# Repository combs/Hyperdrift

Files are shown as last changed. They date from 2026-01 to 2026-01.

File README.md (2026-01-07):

Hyperdrift is a panelized LED matrix artwork.

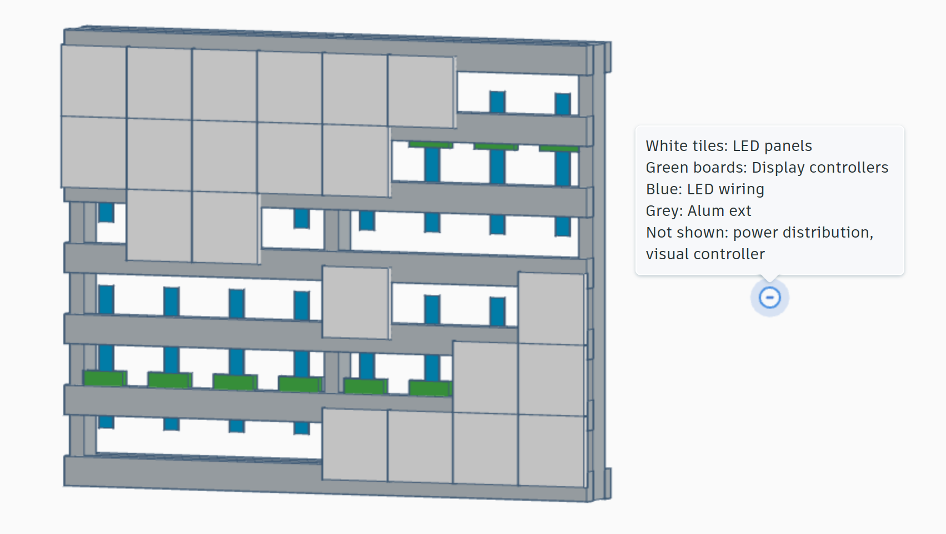
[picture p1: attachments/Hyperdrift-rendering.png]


# LED panels
Each panel can have an arbitrary layout of LEDs, as long as they are electrically connected in a 4x16 matrix (4 common cathodes, 16 anodes).

## Mechanical specification

- [Spec PDF](https://github.com/combs/Hyperdrift/raw/refs/heads/main/Mechanical%20specs/Hyperdrift-Mechanical%20spec%20for%20LED%20panels.pdf) 

## Example LED panel layouts

### Grid
This is a straightforward grid of 8x8 pixels.
- [KiCad board and schematic](https://github.com/combs/Hyperdrift/tree/main/LED%20panel%20reference%20design%20-%20Grid)
- [BOM](https://github.com/combs/Hyperdrift/raw/refs/heads/main/LED%20panel%20reference%20design%20-%20Grid/bom/ibom.html) (download and open)
- [Schematic PDF](https://github.com/combs/Hyperdrift/raw/refs/heads/main/LED%20panel%20reference%20design%20-%20Grid/Hyperdrift-Grid.pdf) 
- [Board PDF](https://github.com/combs/Hyperdrift/raw/refs/heads/main/LED%20panel%20reference%20design%20-%20Grid/plots/Hyperdrift-Grid__Assembly.pdf) 

# Display controllers

Each display controller is a 75x100mm board that drives three LED panels (12x16 matrix arrangement). It accepts 12V in. It is designed to allow for either daisy-chained or wagon-wheel bus arrangement.

- [KiCad board and schematic](https://github.com/combs/Hyperdrift/tree/main/Display%20controller)
- [BOM](https://github.com/combs/Hyperdrift/raw/refs/heads/main/Display%20controller/bom/ibom.html) (download and open)
- [Schematic PDF](https://github.com/combs/Hyperdrift/raw/refs/heads/main/Display%20controller/Hyperdrift-Display-Controller.pdf) 
- [Board PDF](https://github.com/combs/Hyperdrift/raw/refs/heads/main/Display%20controller/Hyperdrift-Display-Controller-board.pdf)

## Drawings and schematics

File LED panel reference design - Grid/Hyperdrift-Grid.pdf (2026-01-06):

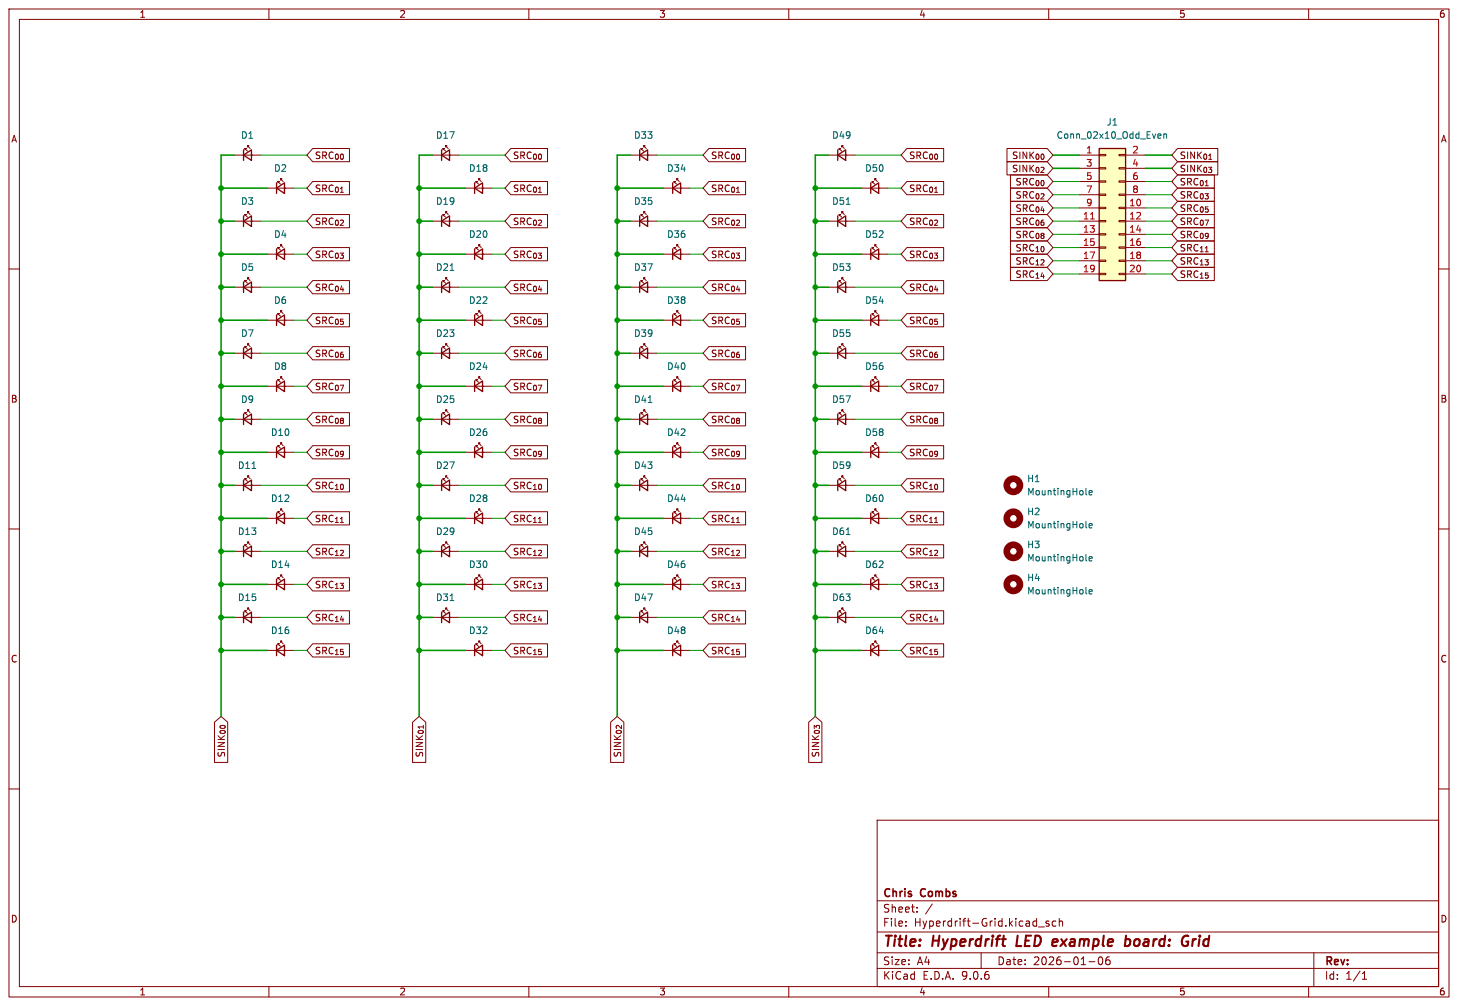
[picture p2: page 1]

Id: 1/1 Title: Hyperdrift LED example board: Grid

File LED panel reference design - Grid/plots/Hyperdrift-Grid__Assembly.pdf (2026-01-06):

A

A

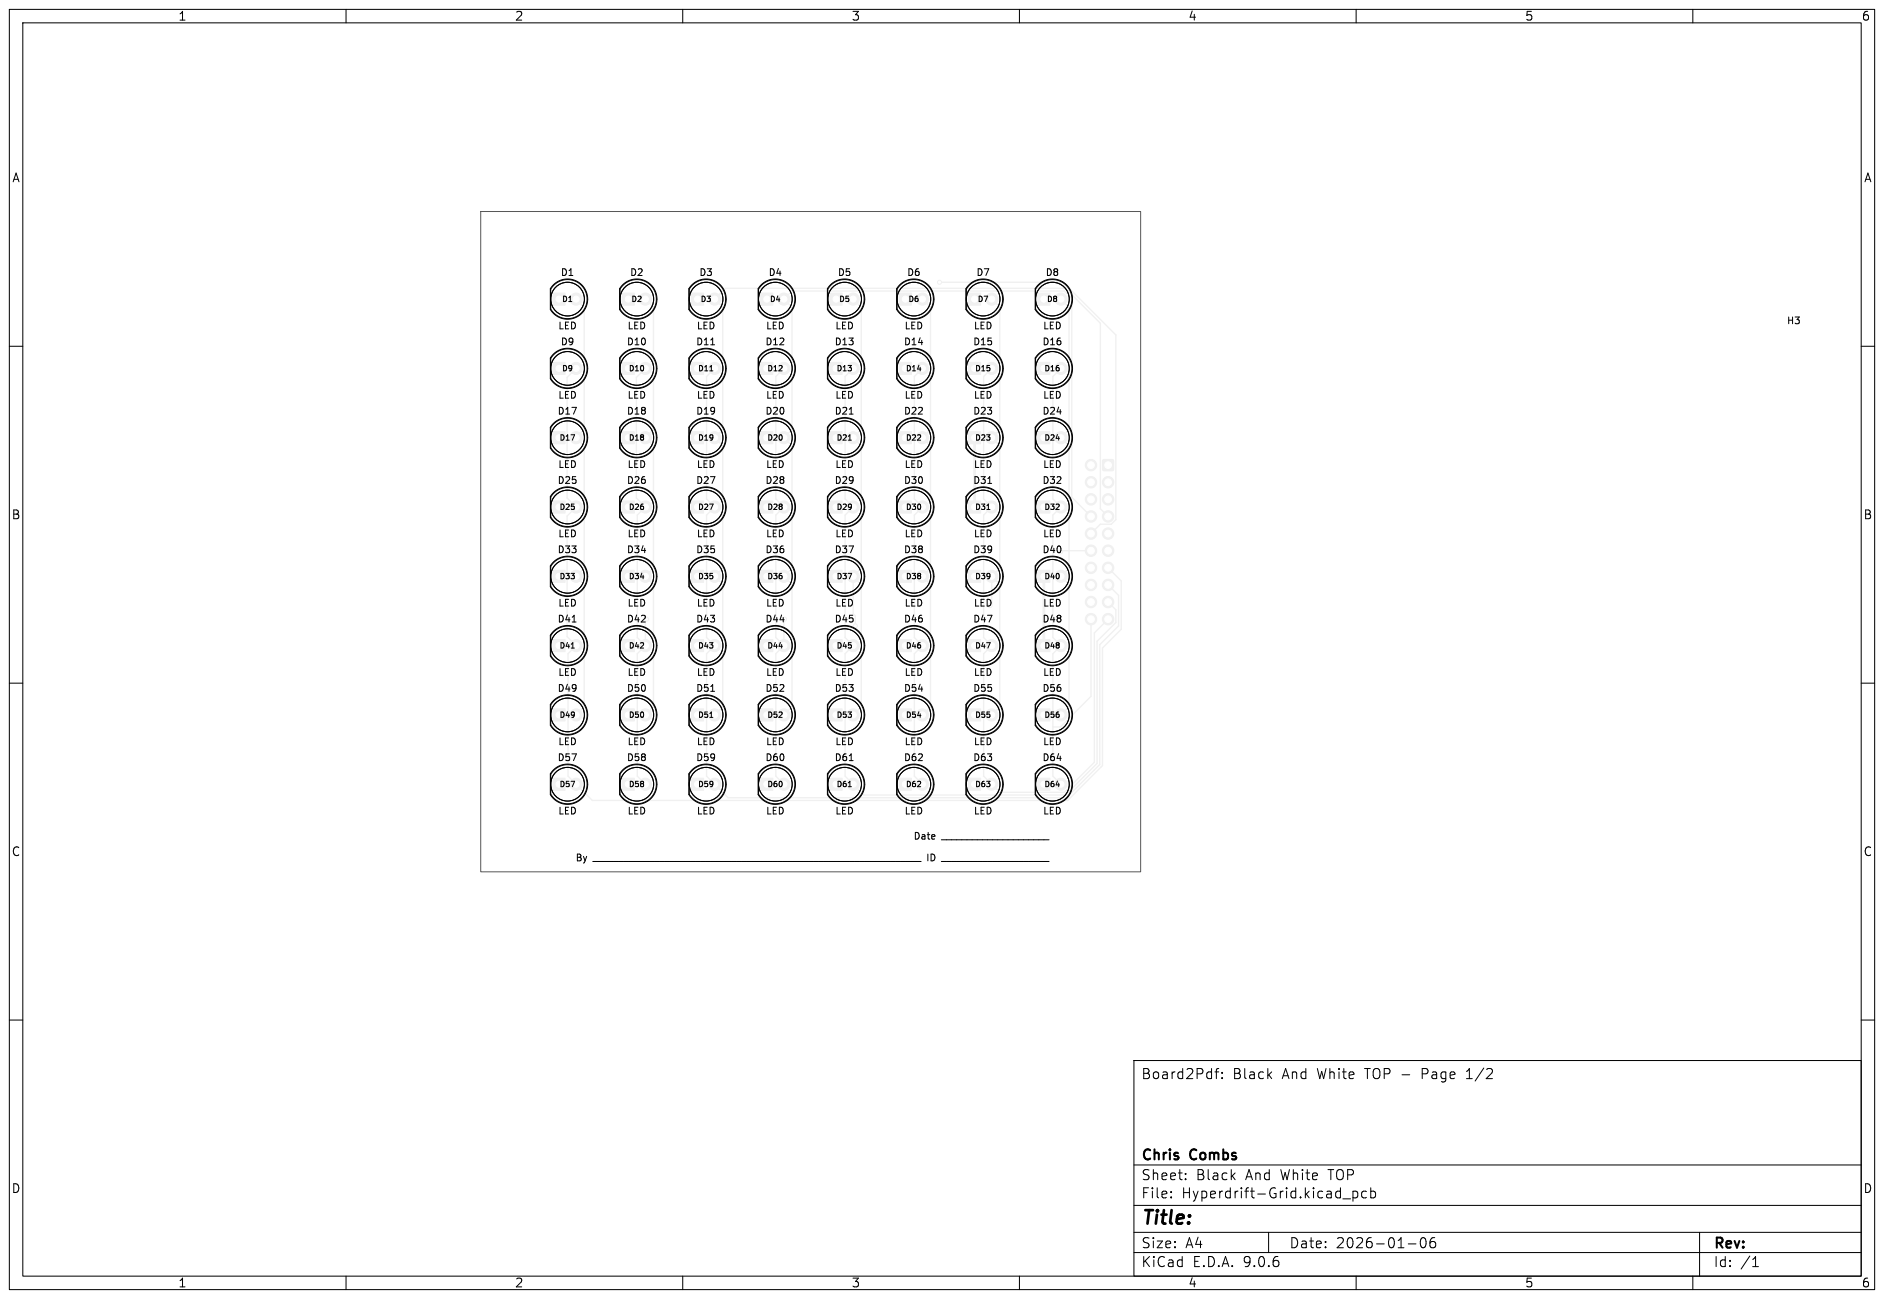
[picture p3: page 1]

J1 1 | 2 | 3 | 4 | 5 | 6

A

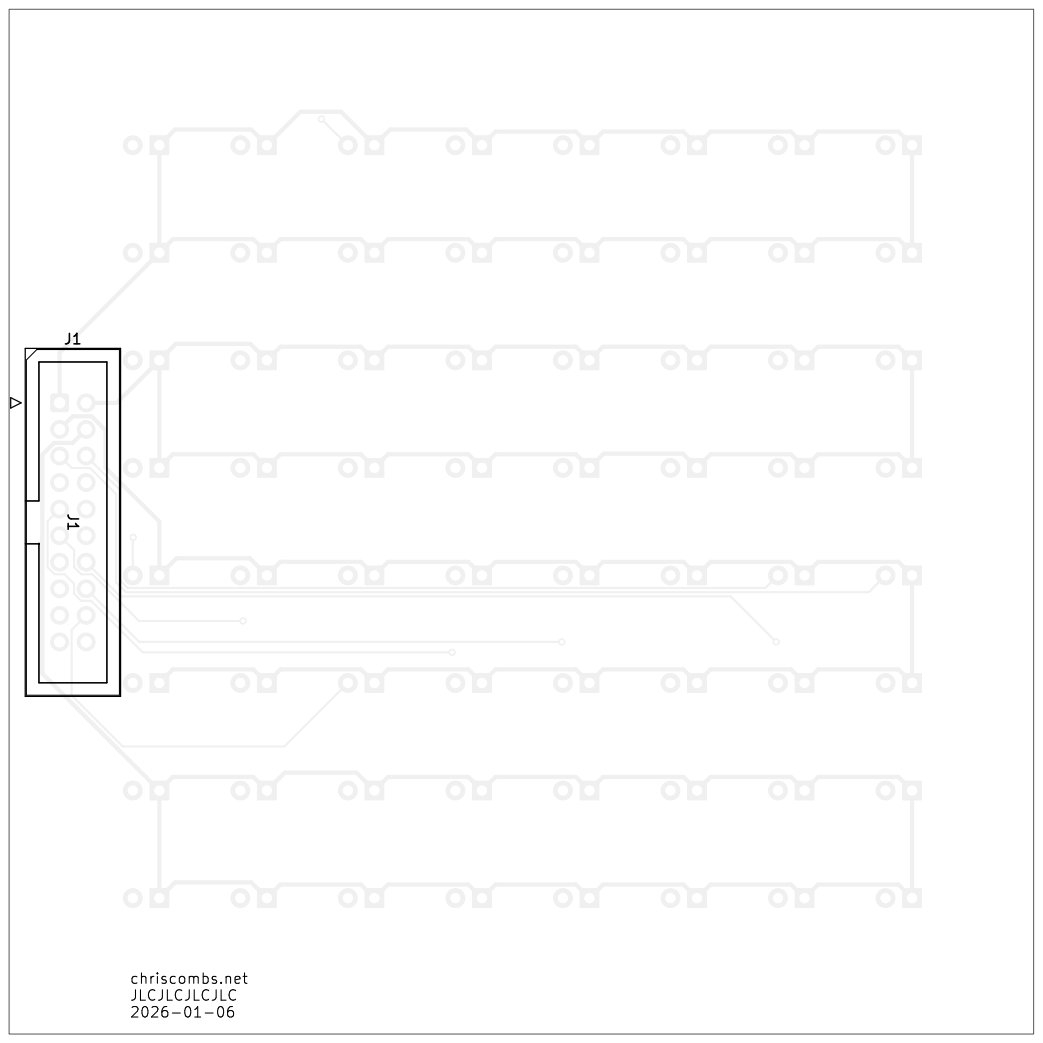
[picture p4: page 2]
D Date: 2026-01-06 KiCad; E.D.A. 9.0.6 Size: A4; Rev:; Id: /1 Title: File: Hyperdrift-Grid.kicad_pcb Sheet: Black; And; White; BOT Chris Combs Board2Pdf:; Black; BOT -; Page 2/2 J1

chriscombs.net JLCJLCJLCJLC

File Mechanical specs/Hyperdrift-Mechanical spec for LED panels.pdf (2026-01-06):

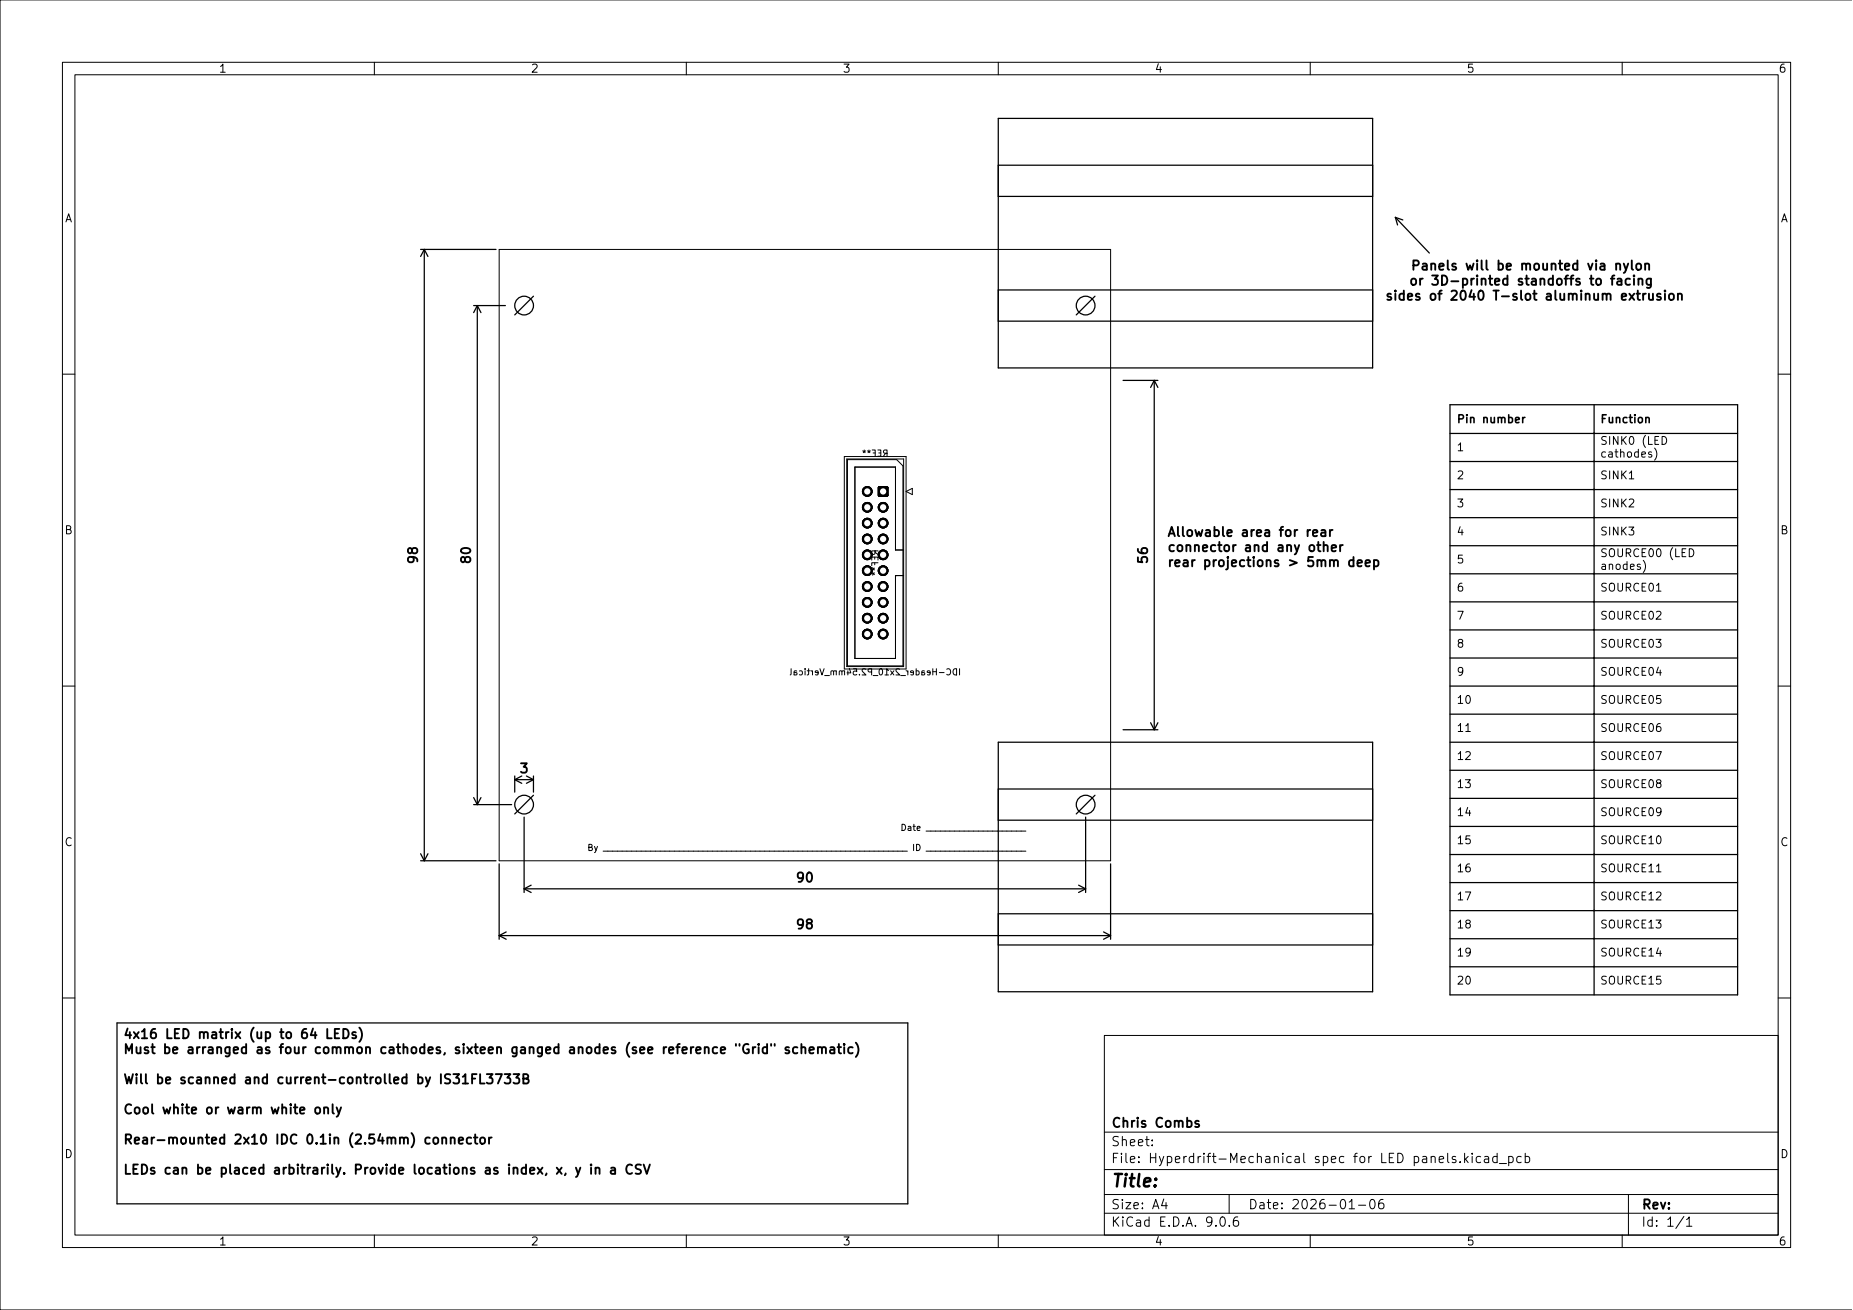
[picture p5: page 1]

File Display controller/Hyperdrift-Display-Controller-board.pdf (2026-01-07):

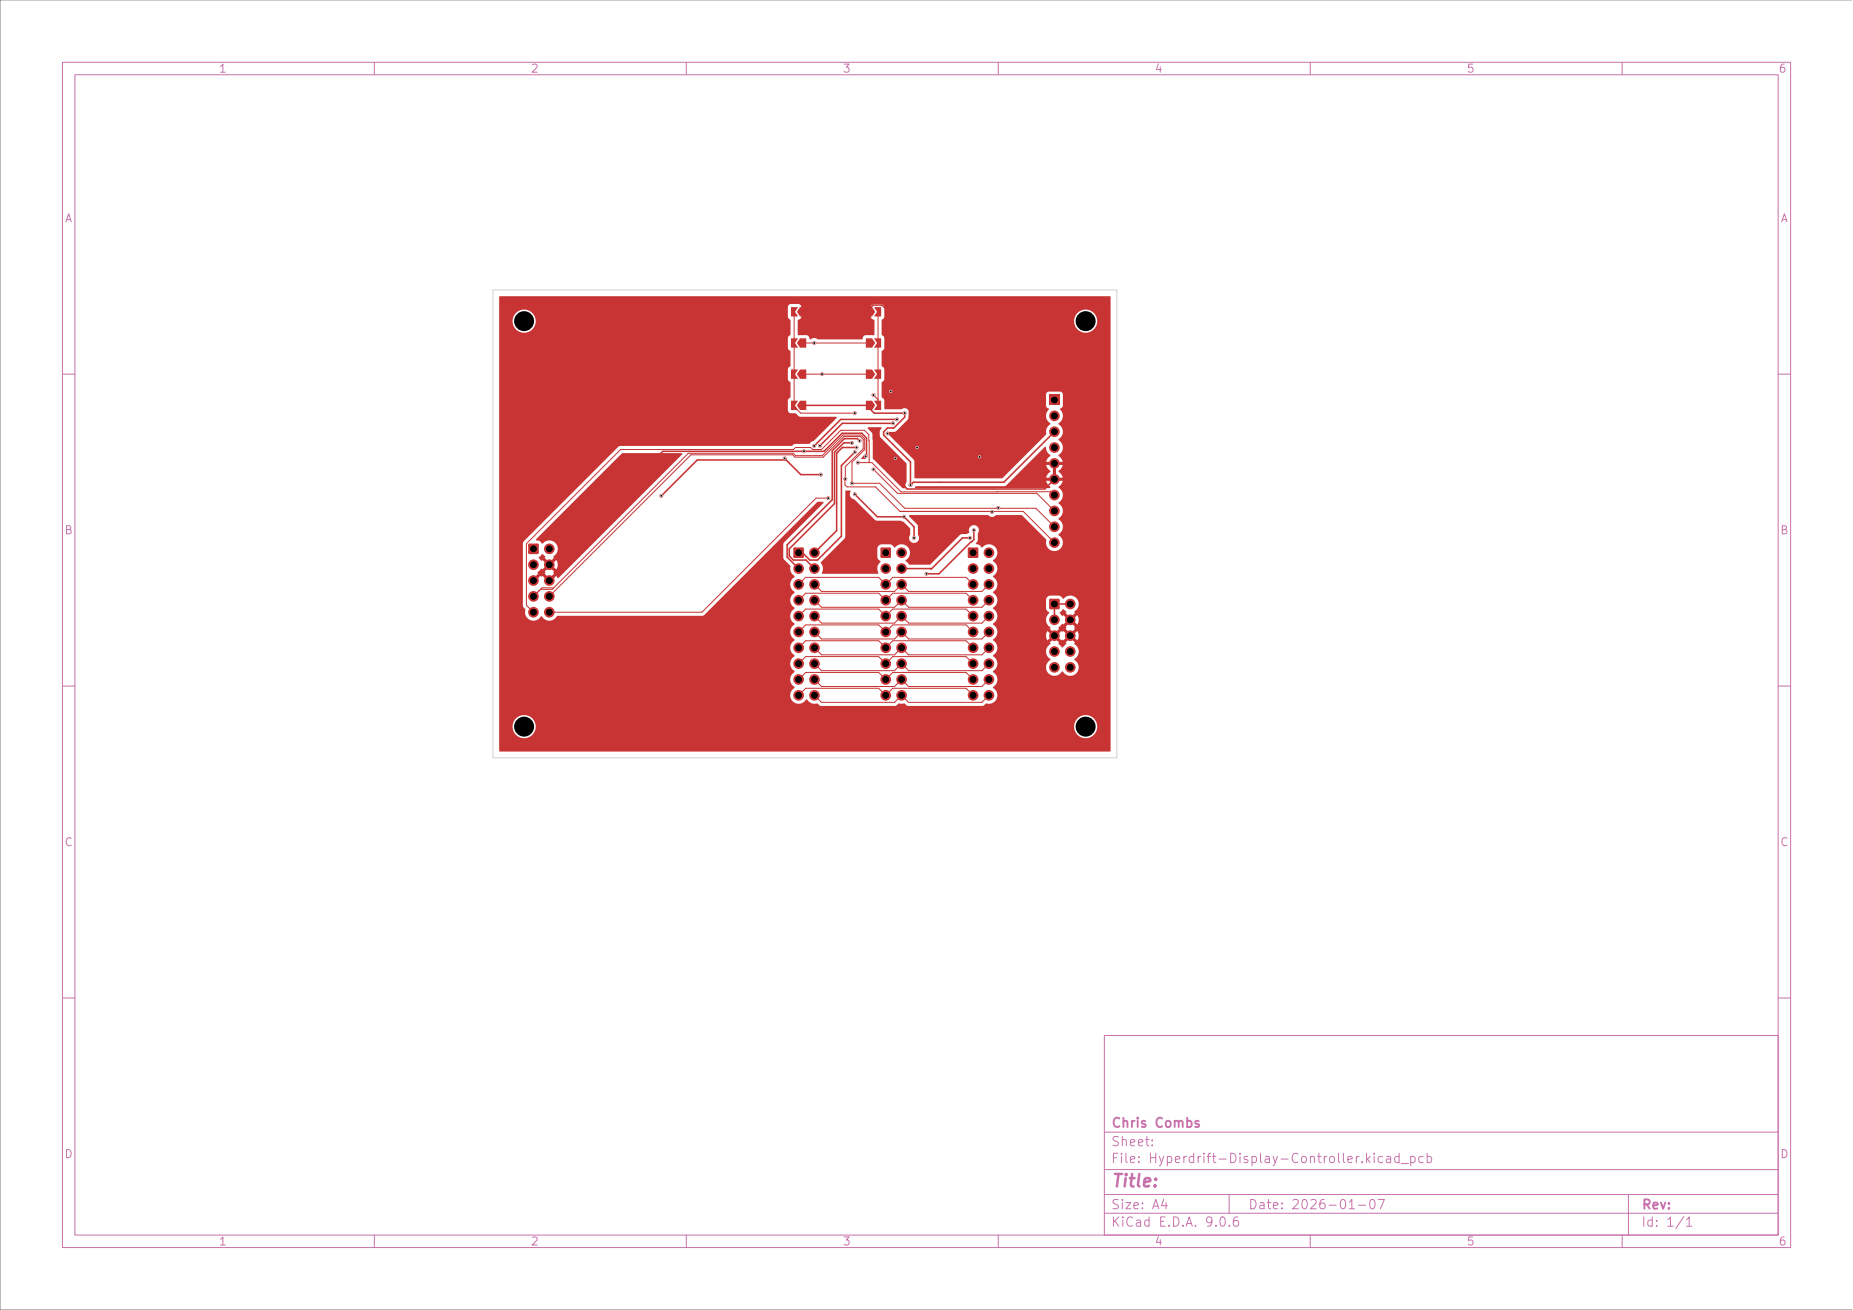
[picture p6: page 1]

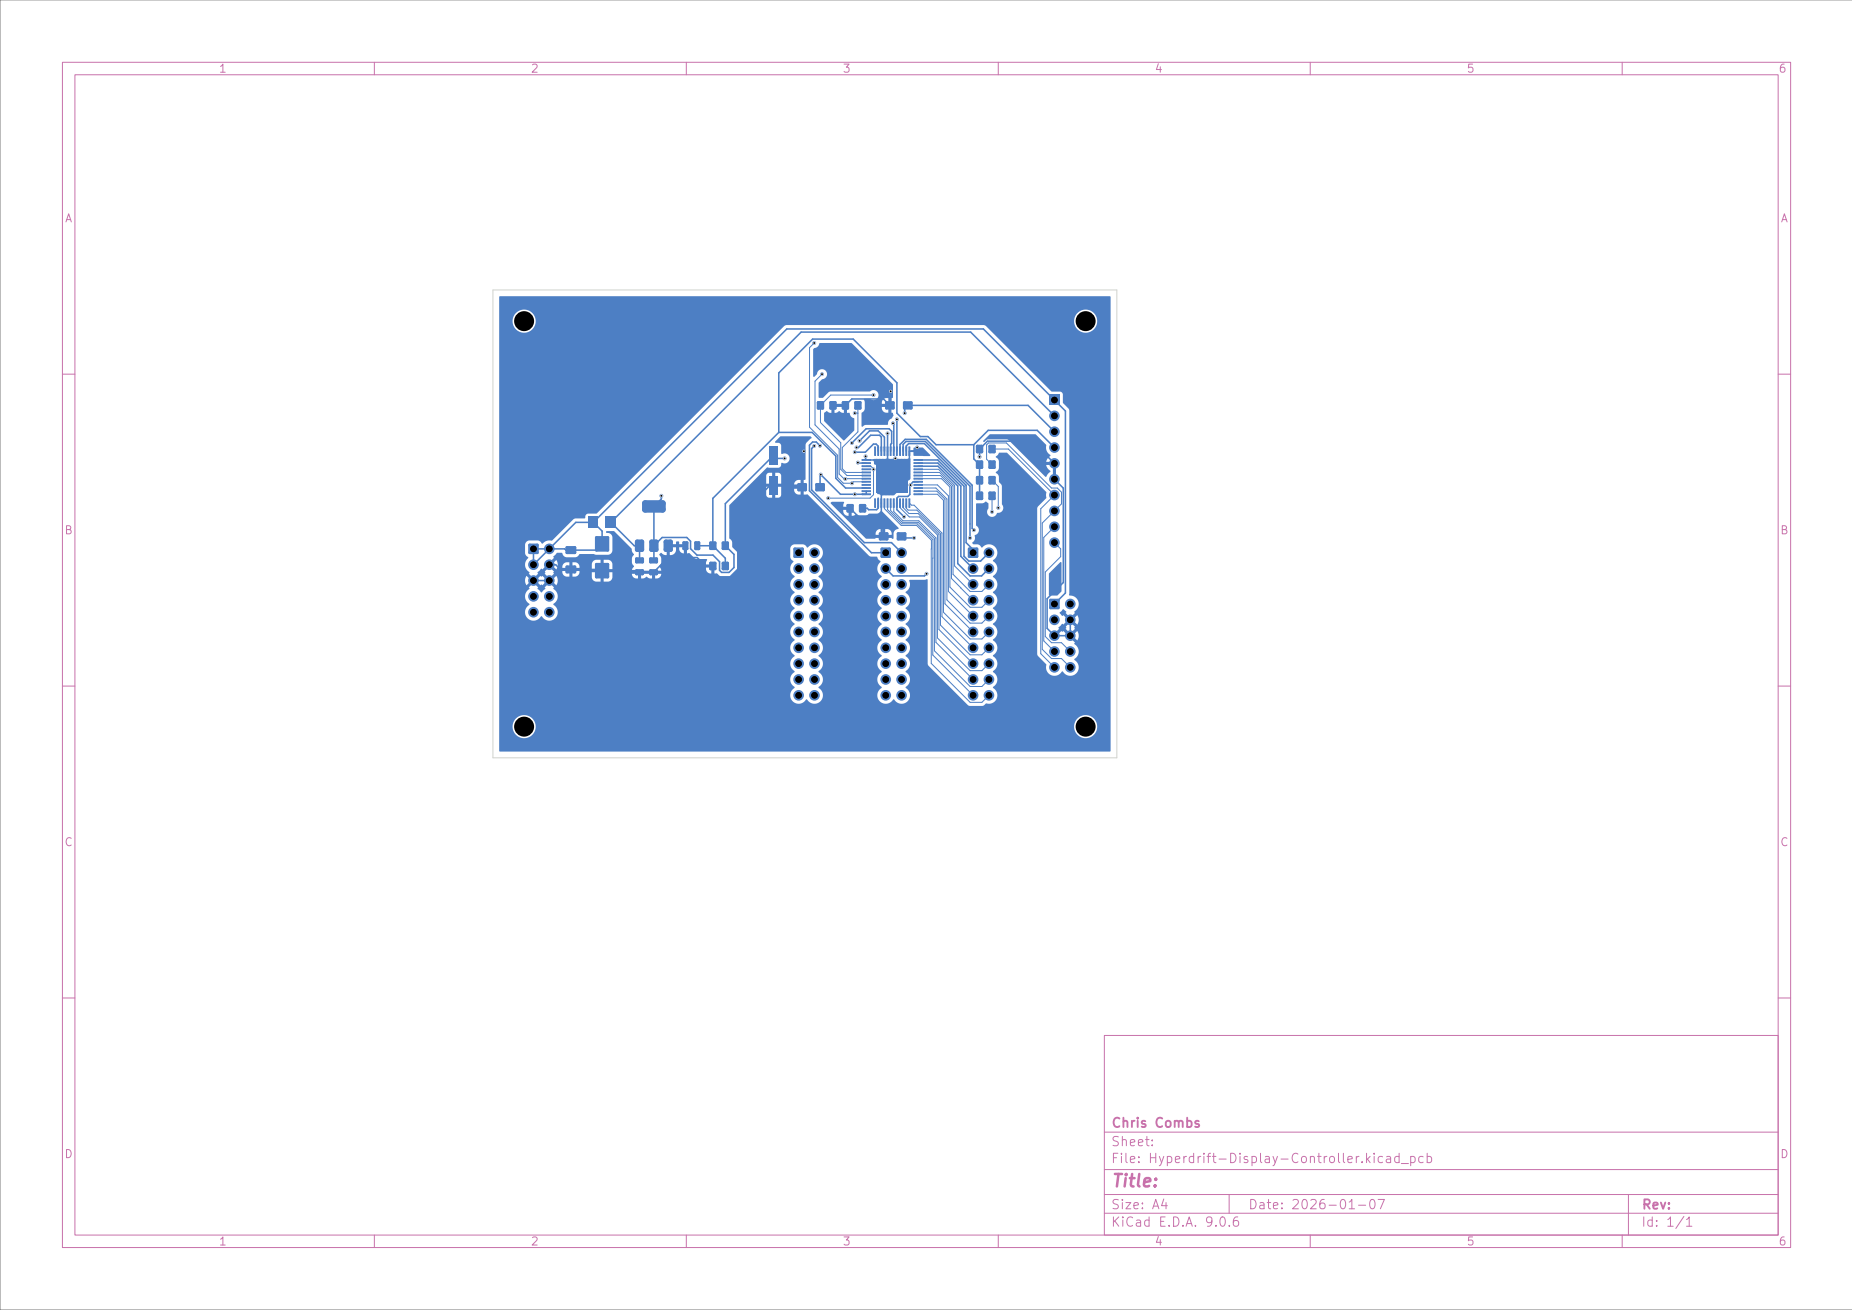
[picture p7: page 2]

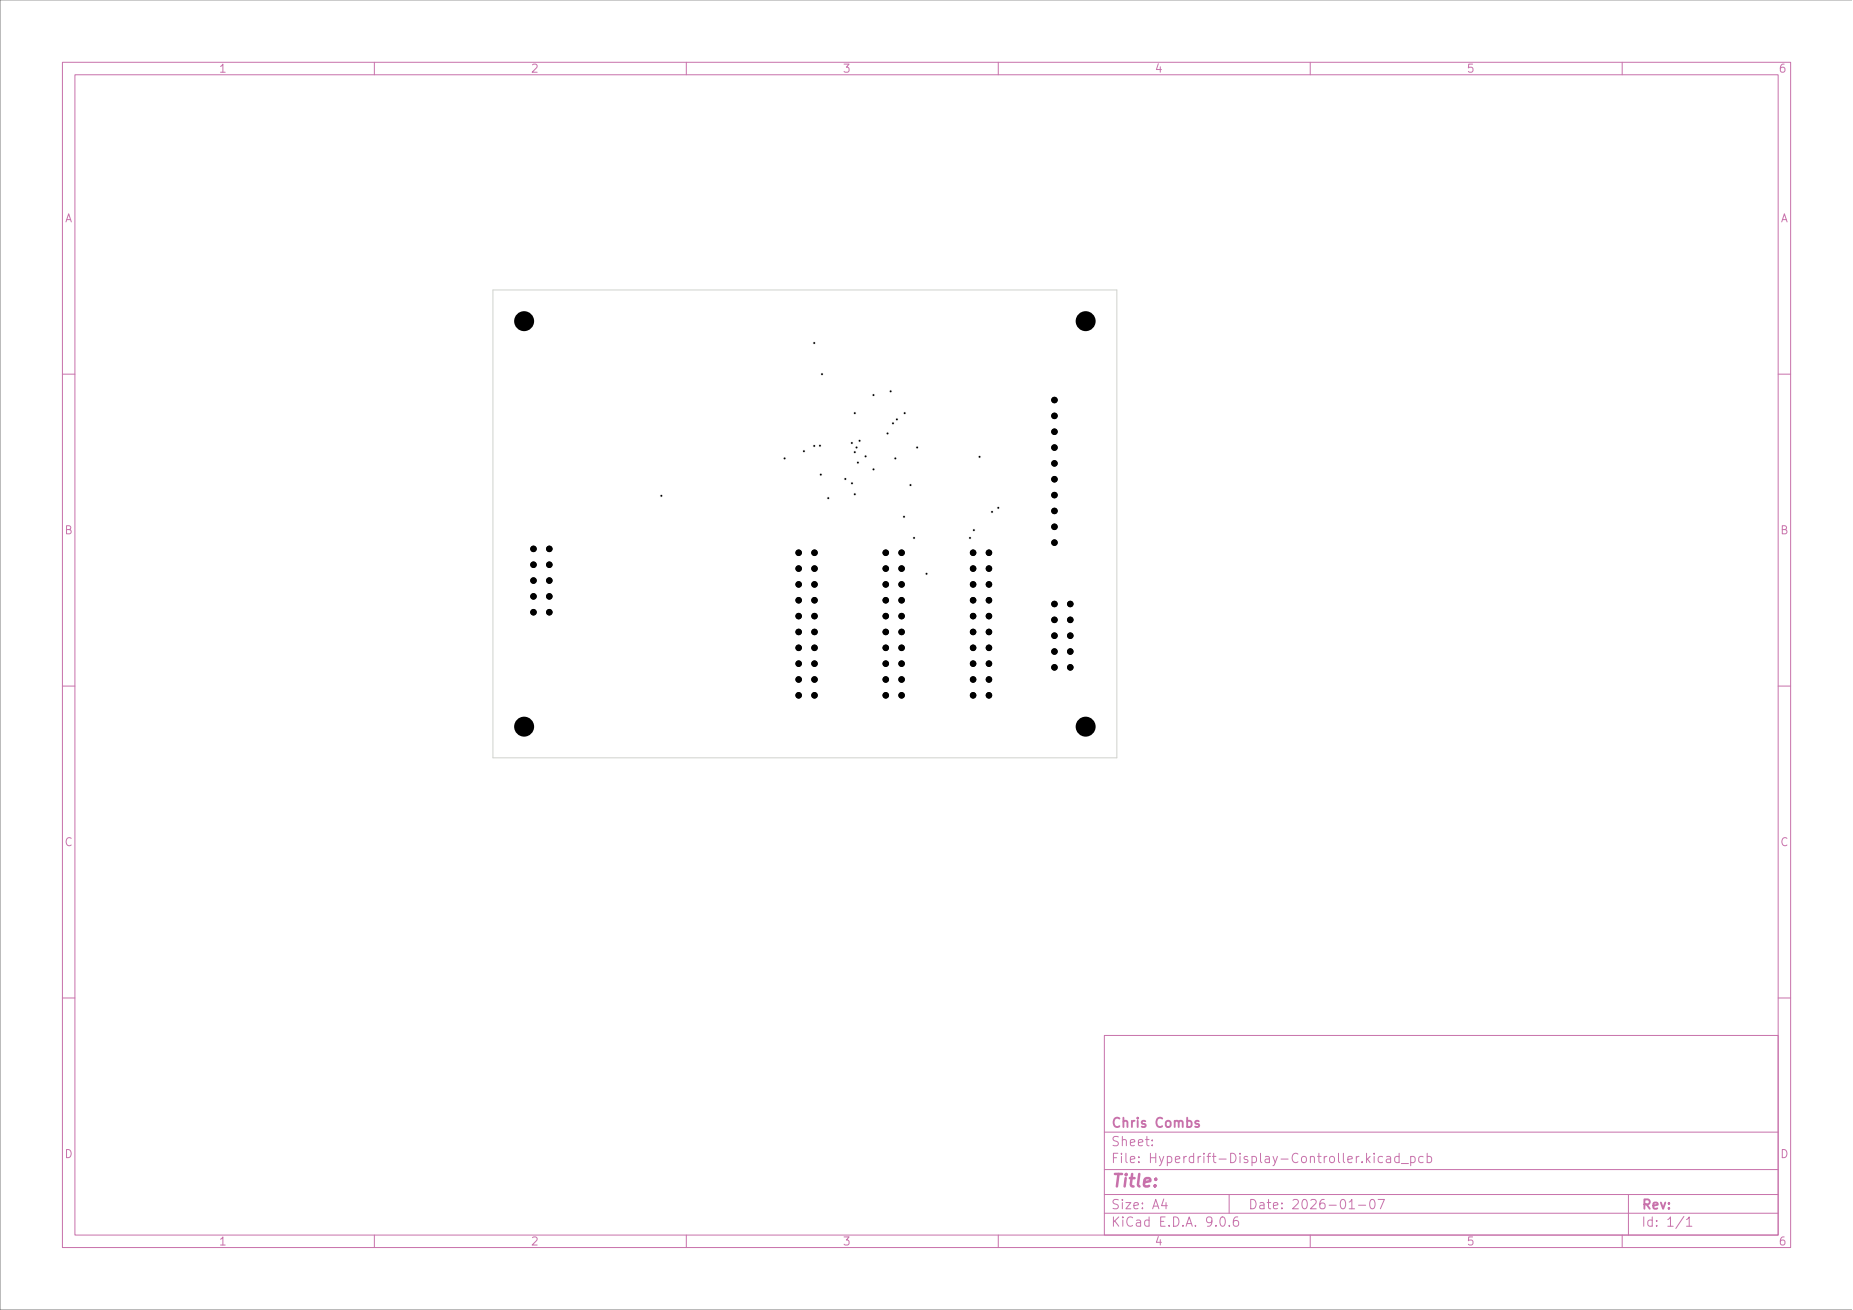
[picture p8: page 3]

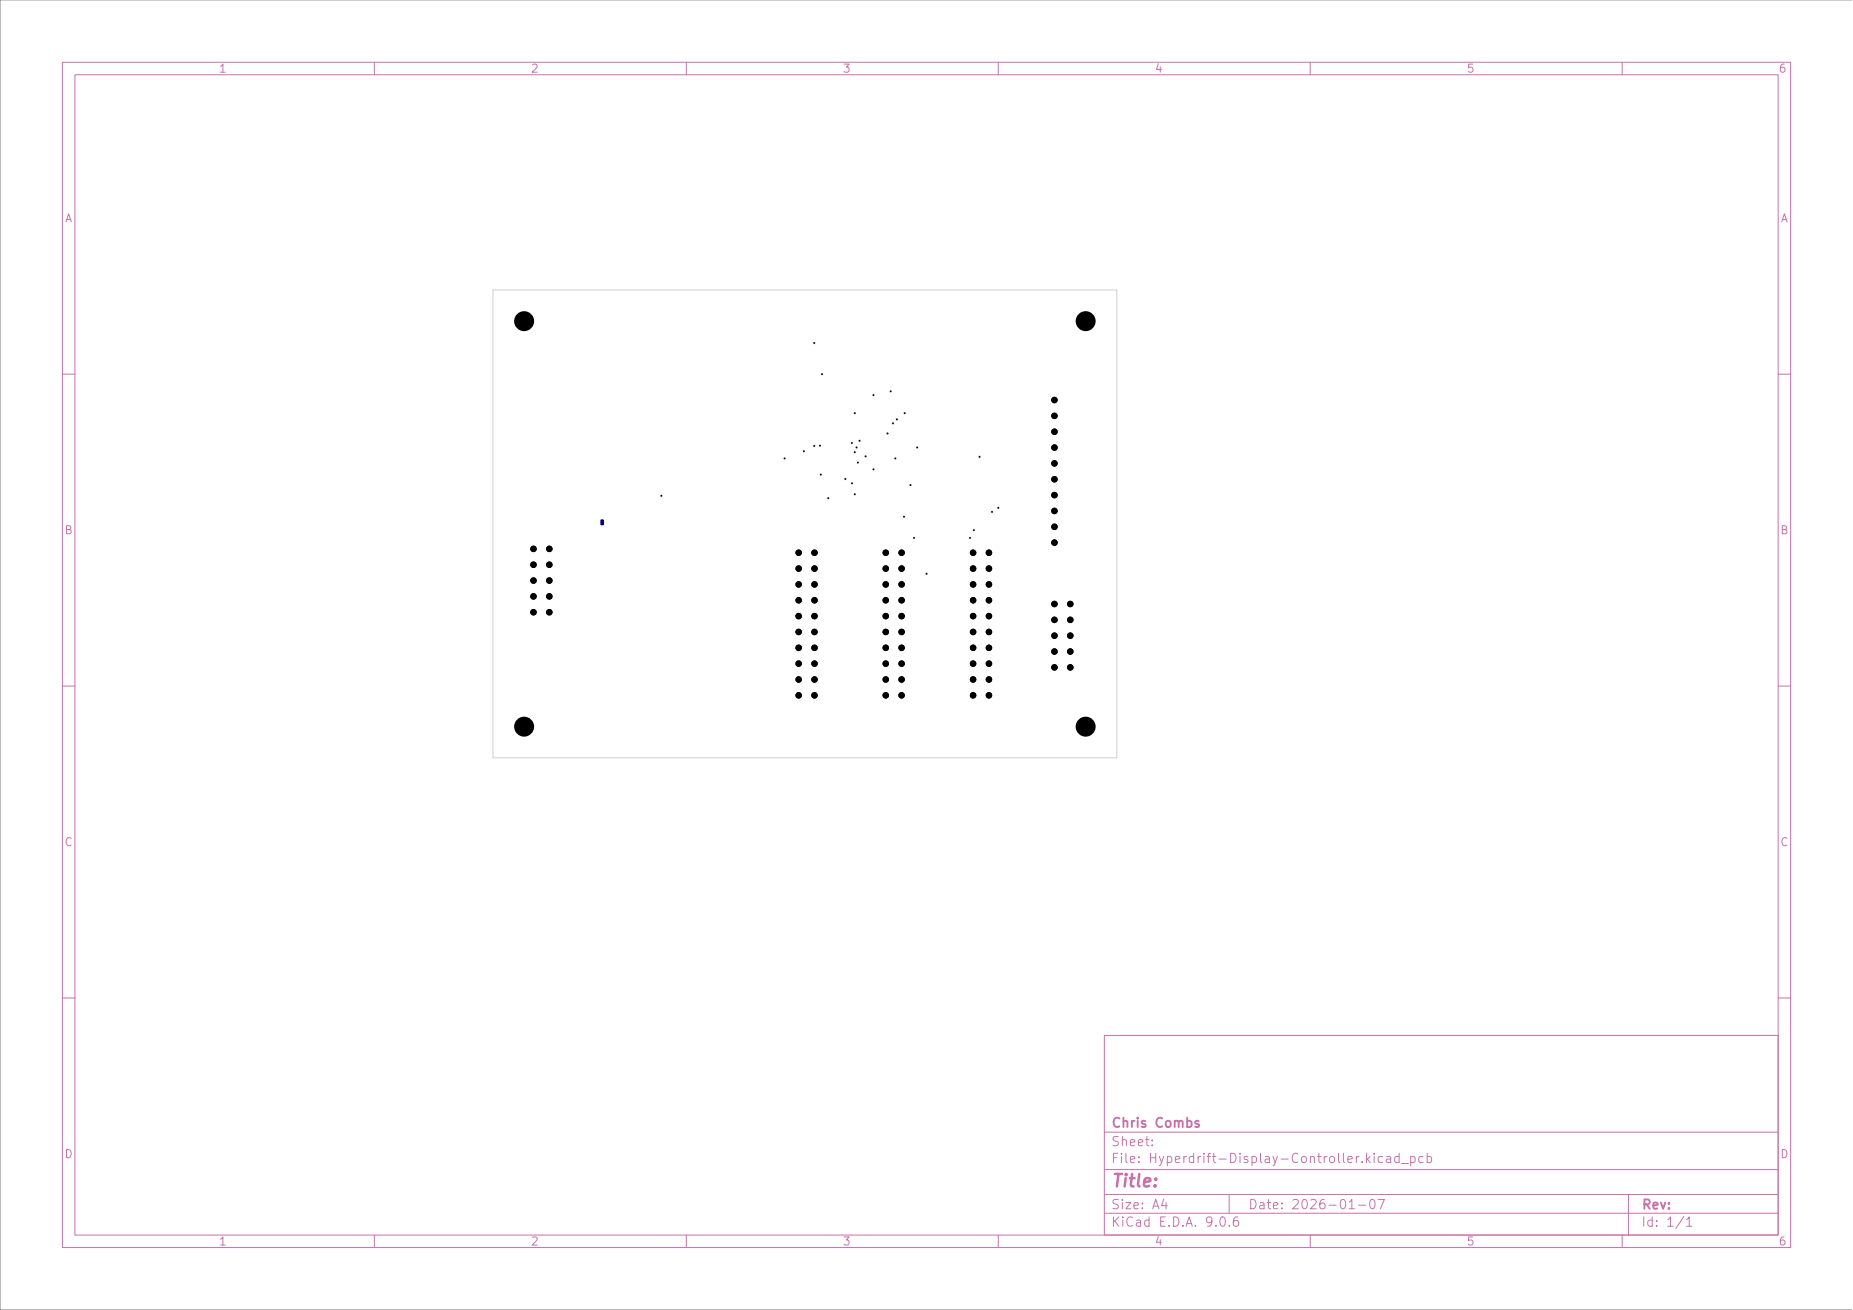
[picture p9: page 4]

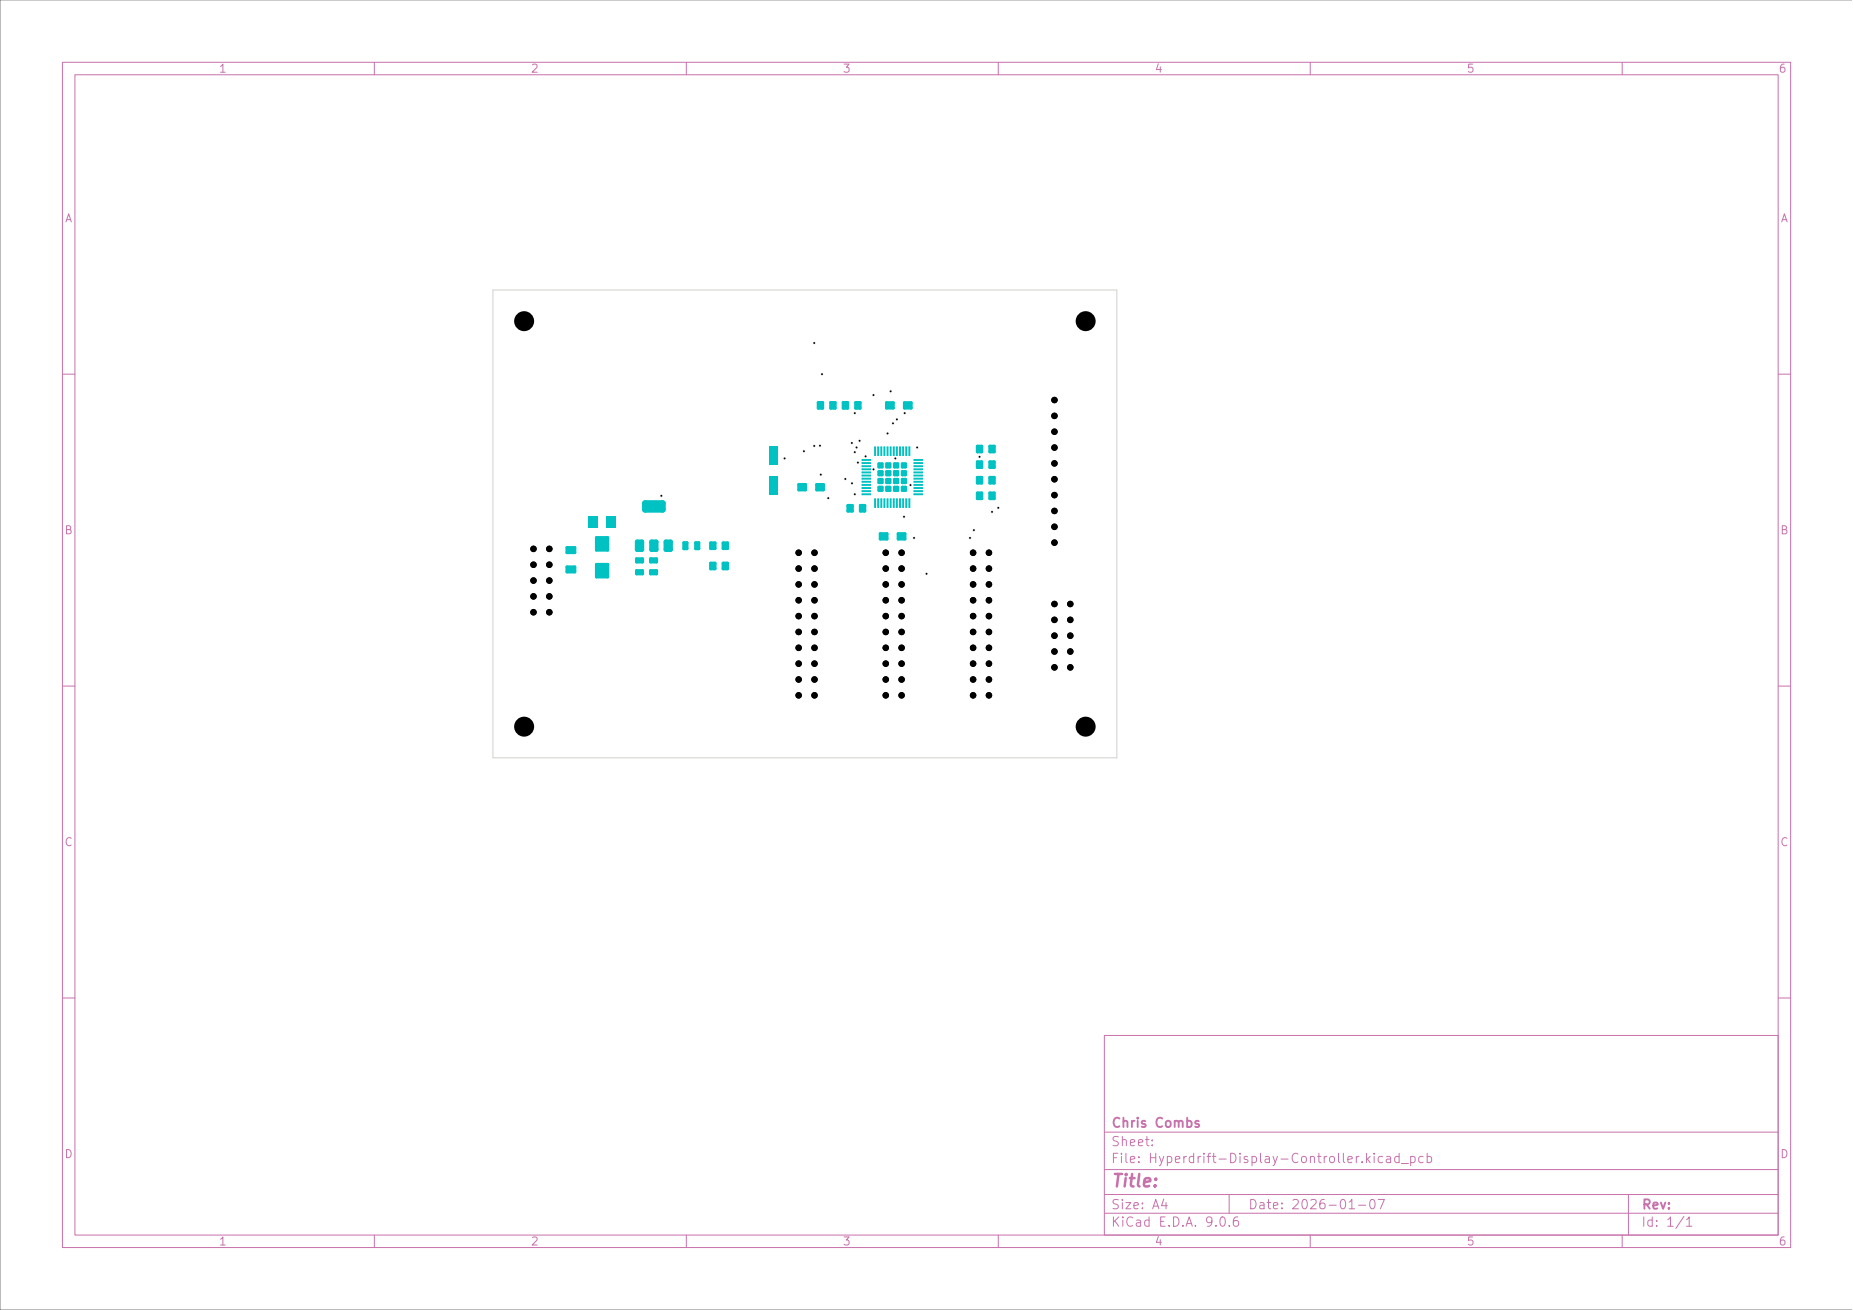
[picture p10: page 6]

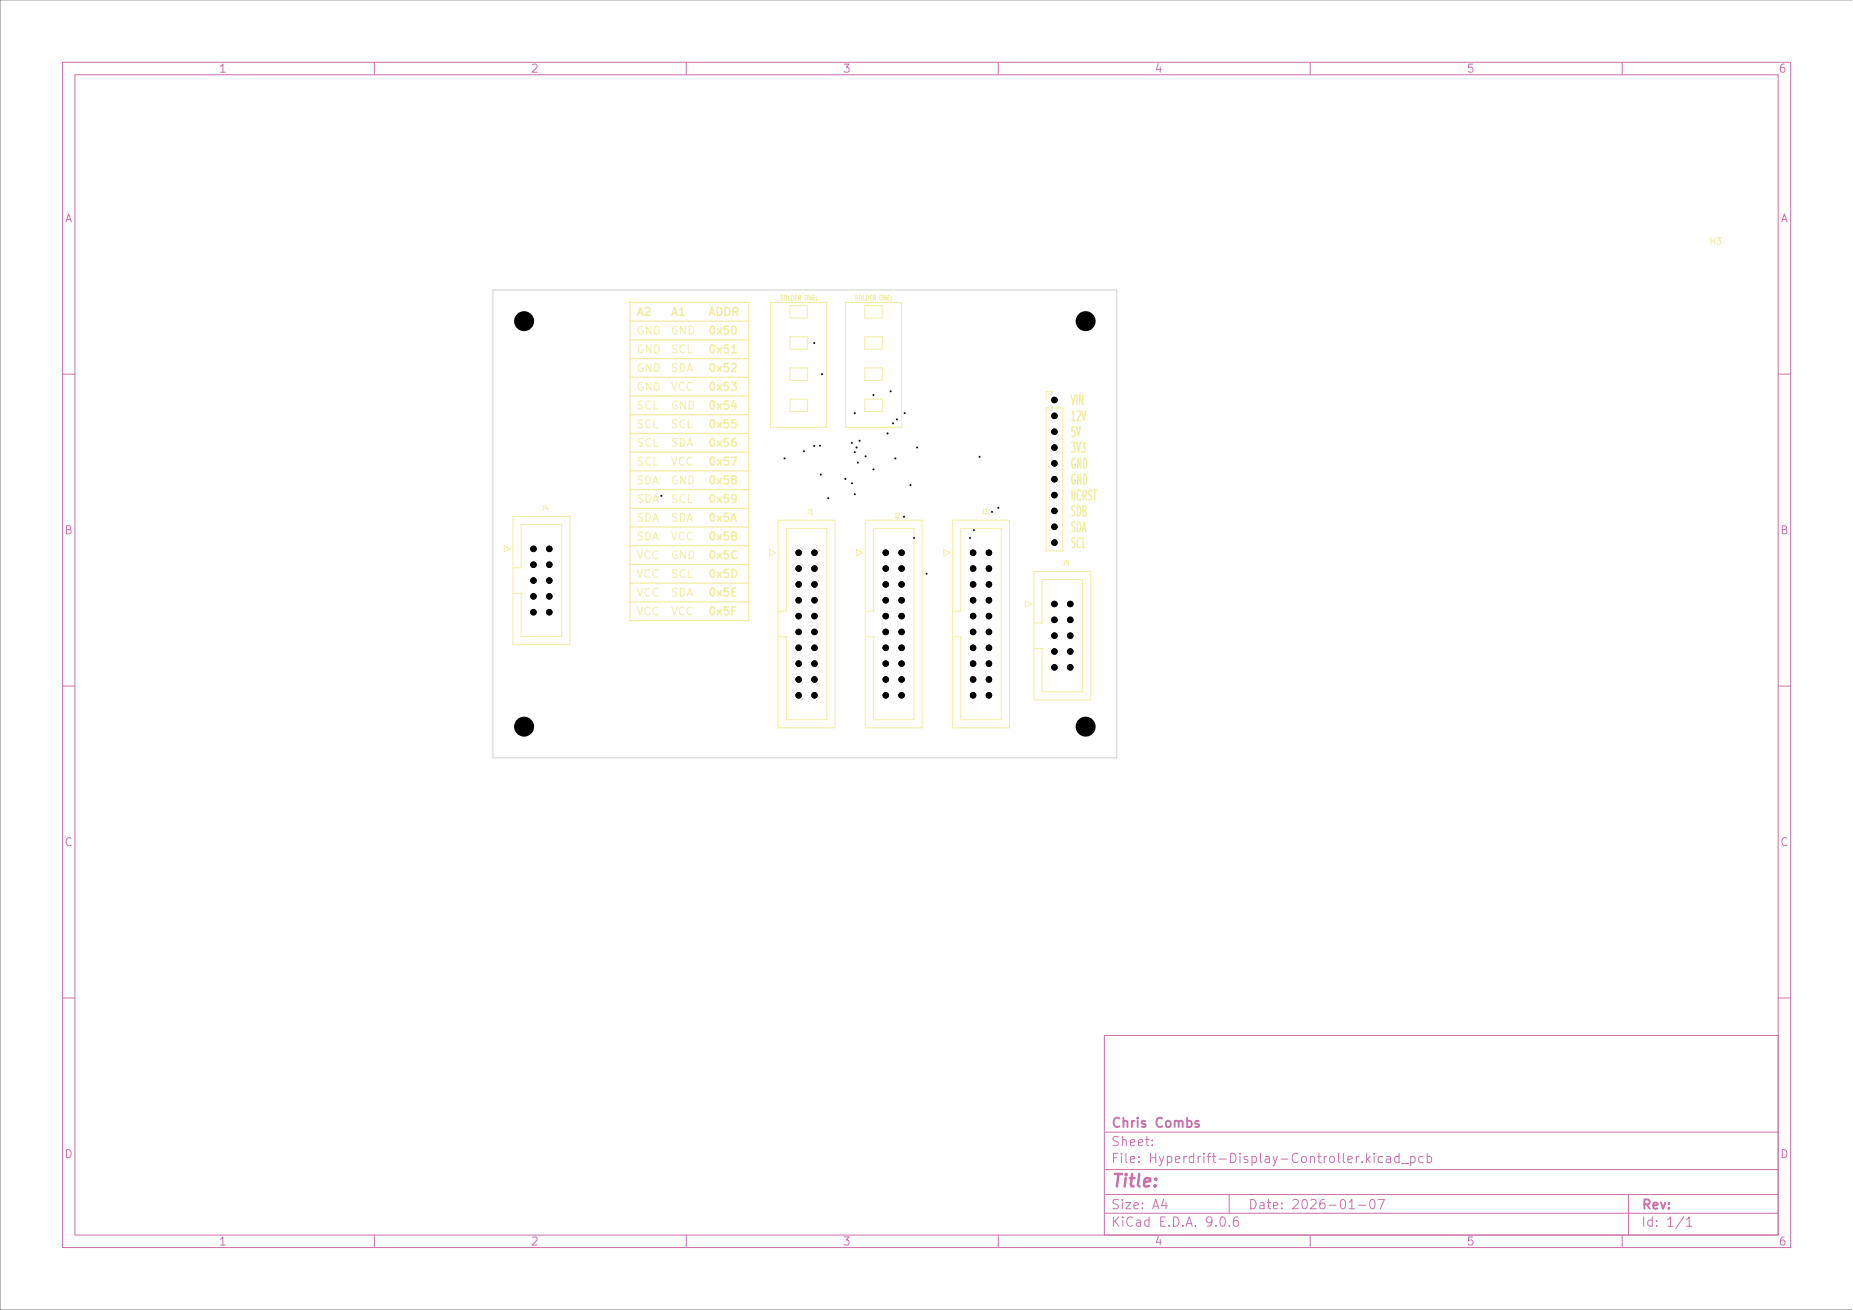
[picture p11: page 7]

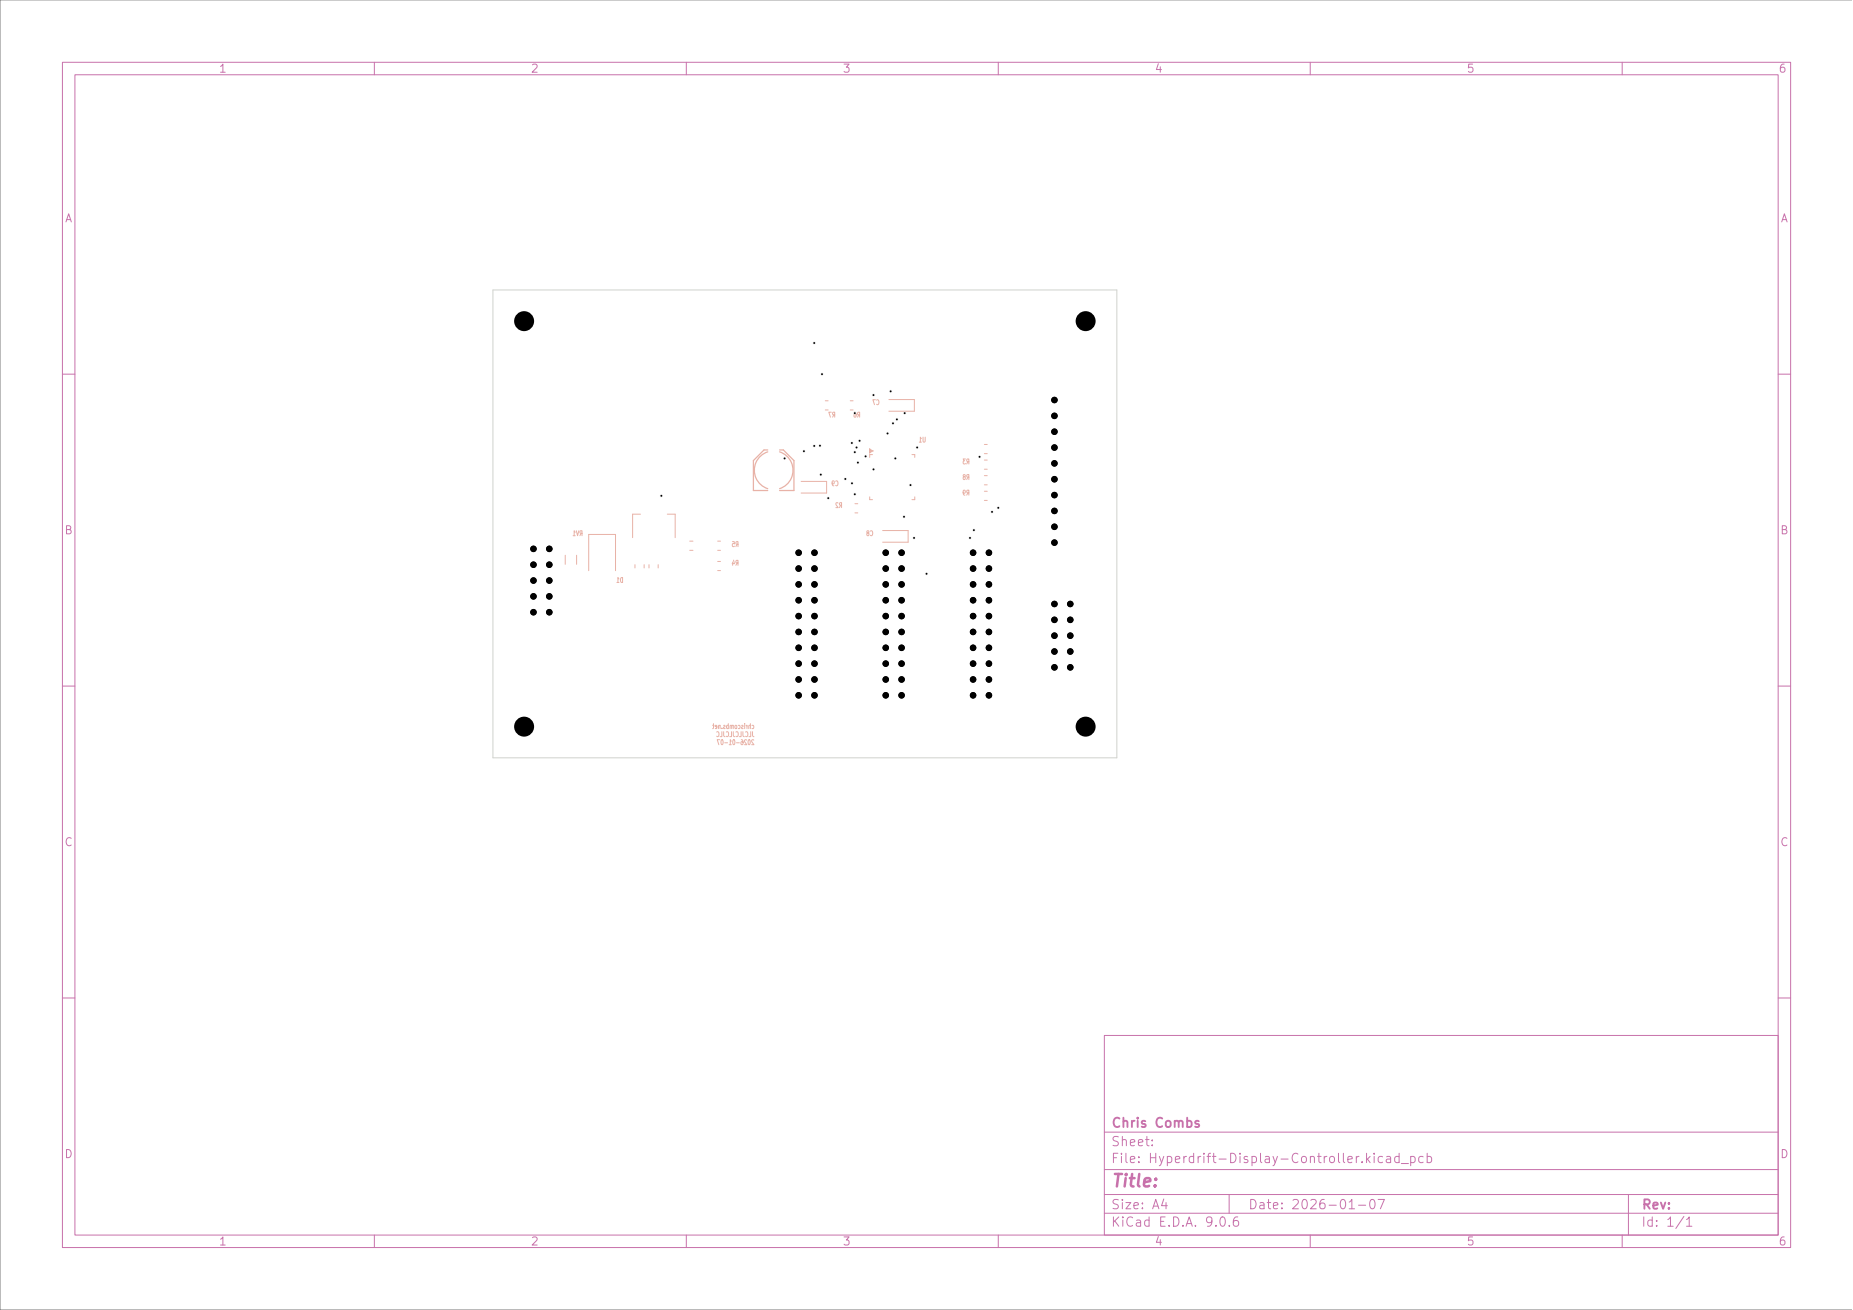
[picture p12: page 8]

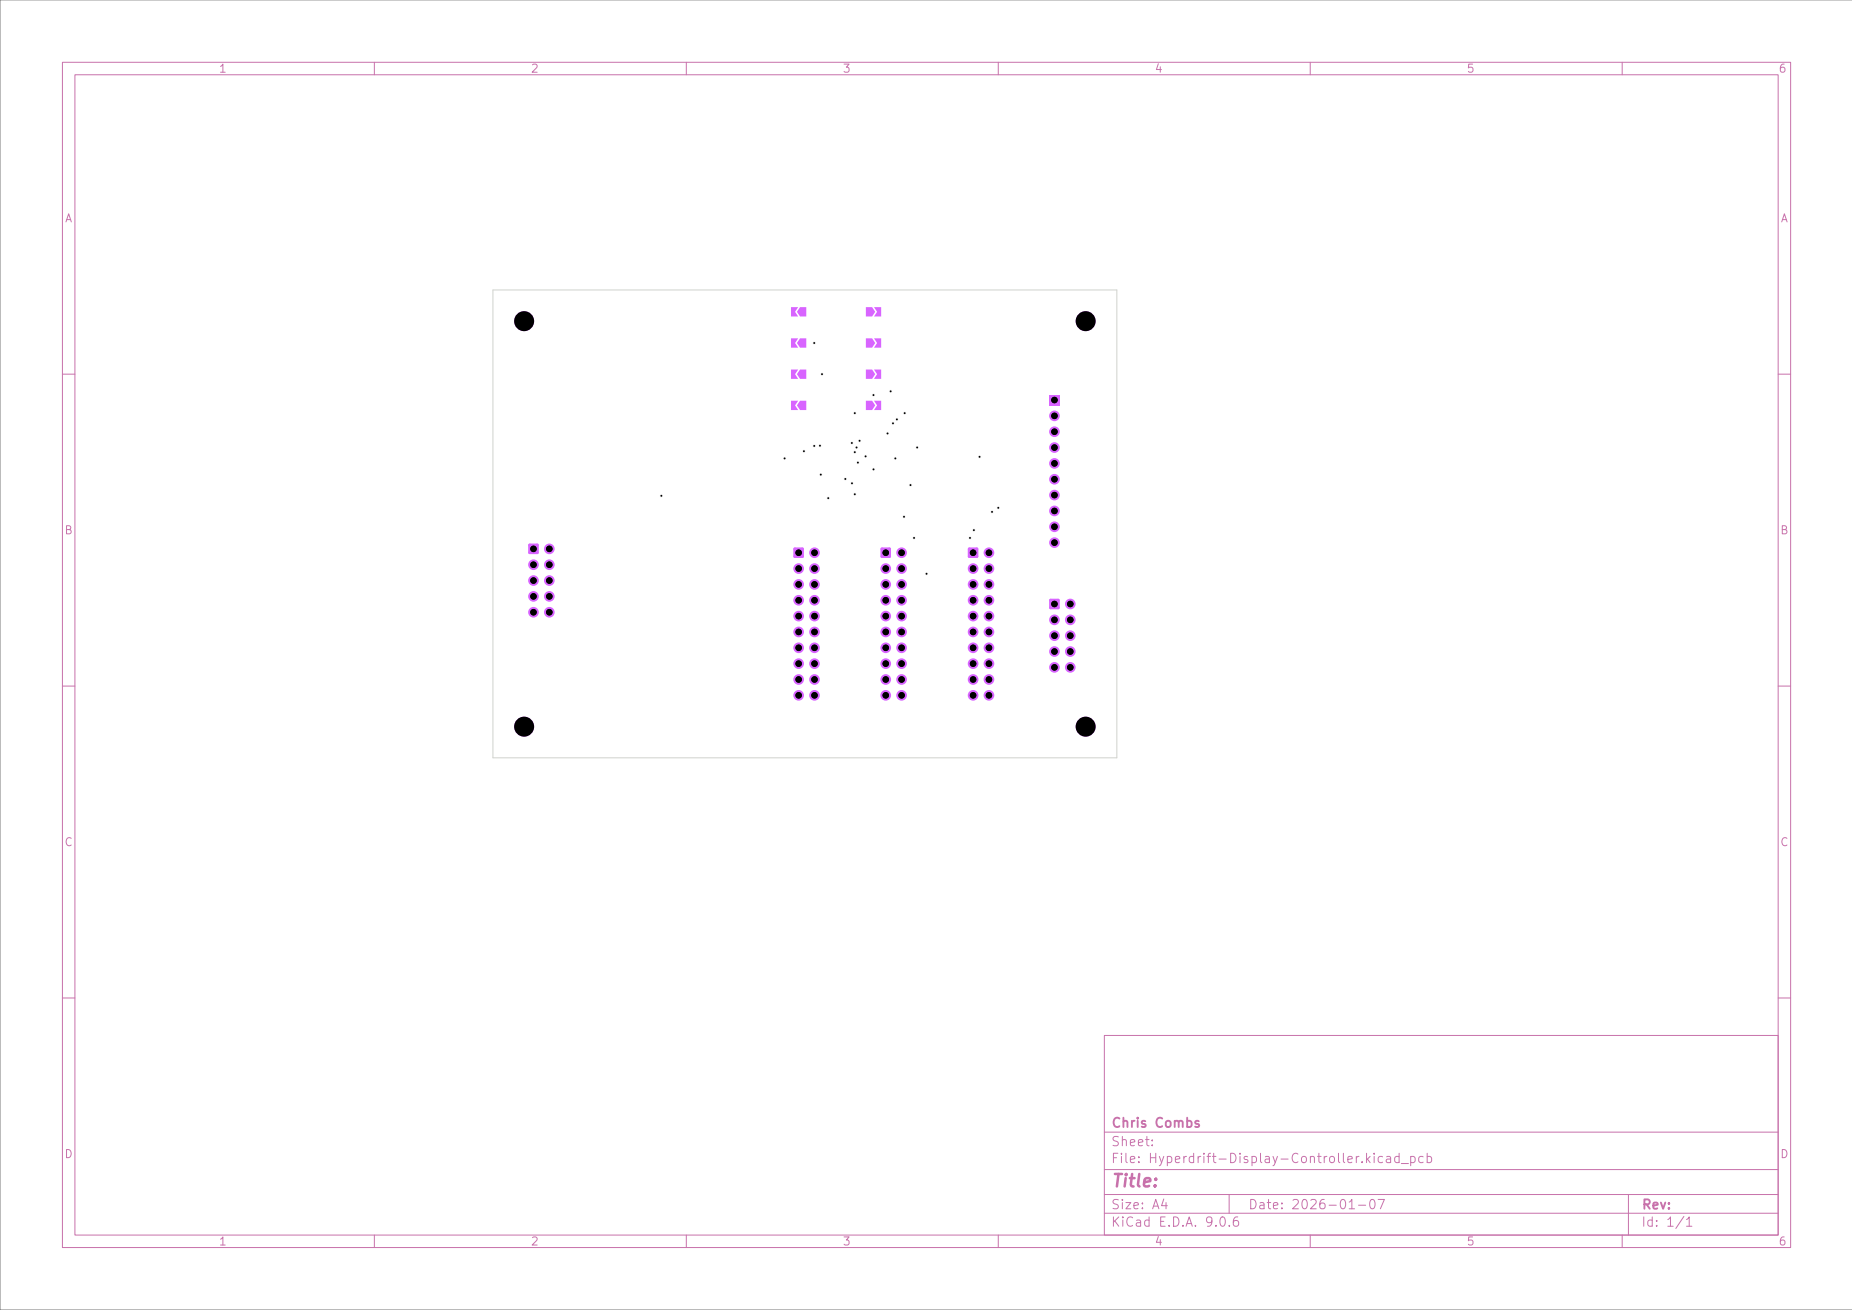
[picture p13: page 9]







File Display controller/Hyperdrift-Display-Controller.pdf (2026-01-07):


VIO 39 SDA 41 SCL 42 ~{INTB} 45 ~{SDB} 46

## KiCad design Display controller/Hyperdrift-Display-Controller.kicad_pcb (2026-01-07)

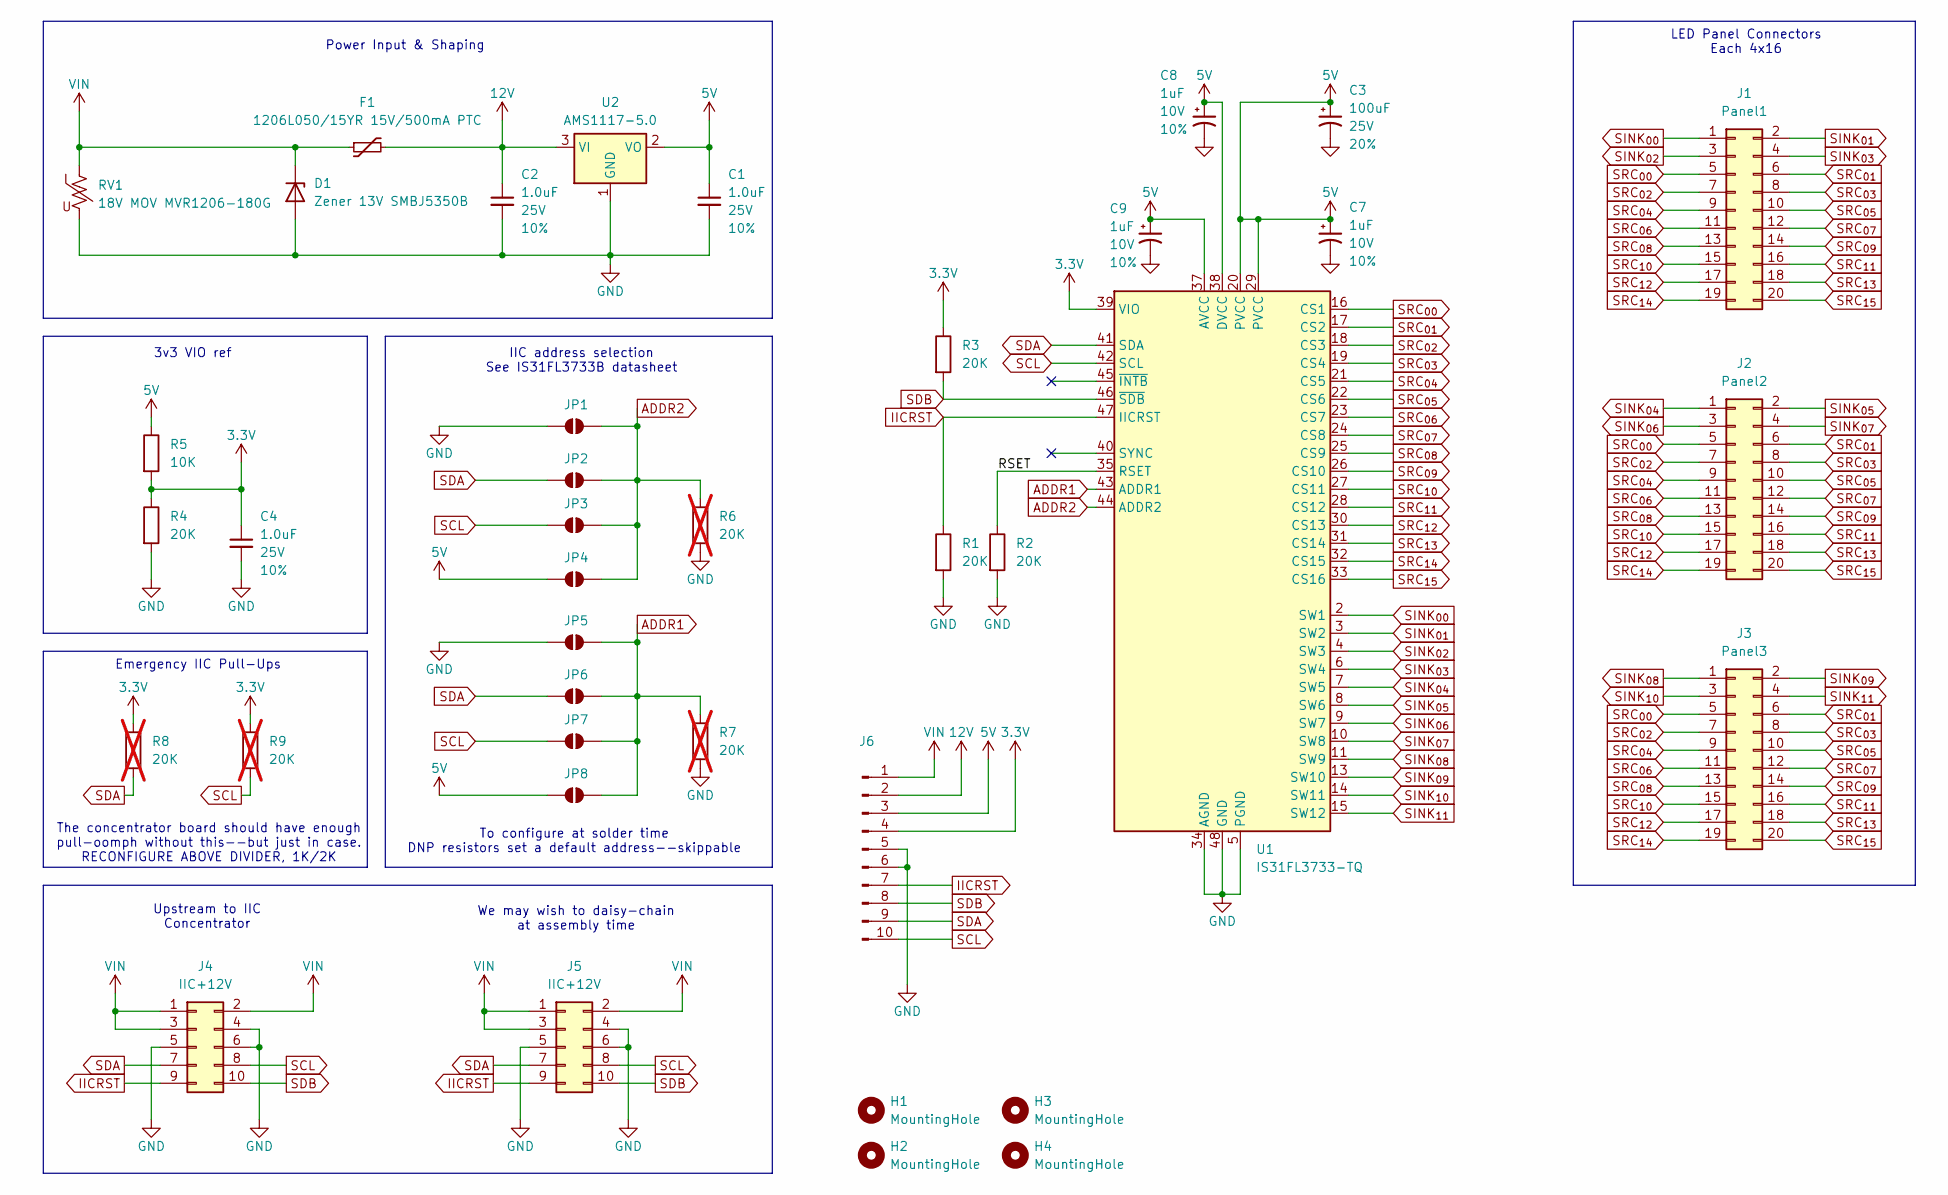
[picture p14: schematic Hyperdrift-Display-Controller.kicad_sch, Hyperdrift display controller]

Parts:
C1, C2, C4: 1.0uF; C_0805_2012Metric; Voltage 25V; Tolerance 10%
C3: 100uF; Panasonic_D; Voltage 25V; Tolerance 20%
C7, C8, C9: 1uF; CP_EIA-3216-10_Kemet-I_Pad1.58x1.35mm_HandSolder; Voltage 10V; Tolerance 10%
D1: Zener 13V SMBJ5350B; D_SMB
F1: 1206L050/15YR 15V/500mA PTC; 1206
H1, H2, H3, H4: MountingHole; MountingHole_3.2mm_M3
J1: Panel1; IDC-Header_2x10_P2.54mm_Vertical
J2: Panel2; IDC-Header_2x10_P2.54mm_Vertical
J3: Panel3; IDC-Header_2x10_P2.54mm_Vertical
J4, J5: IIC+12V; IDC-Header_2x05_P2.54mm_Vertical
J6: Conn_01x10_Pin; PinHeader_1x10_P2.54mm_Vertical
JP1: ADDR2 GND; SolderJumper-2_P1.3mm_Open_TrianglePad1.0x1.5mm
JP2: ADDR2 SDA; SolderJumper-2_P1.3mm_Open_TrianglePad1.0x1.5mm
JP3: ADDR2 SCL; SolderJumper-2_P1.3mm_Open_TrianglePad1.0x1.5mm
JP4: ADDR VCC; SolderJumper-2_P1.3mm_Open_TrianglePad1.0x1.5mm
JP5: ADDR1 GND; SolderJumper-2_P1.3mm_Open_TrianglePad1.0x1.5mm
JP6: ADDR1 SDA; SolderJumper-2_P1.3mm_Open_TrianglePad1.0x1.5mm
JP7: ADDR1 SCL; SolderJumper-2_P1.3mm_Open_TrianglePad1.0x1.5mm
JP8: ADDR1 VCC; SolderJumper-2_P1.3mm_Open_TrianglePad1.0x1.5mm
R1, R2, R3, R4: 20K; R_0805_2012Metric_Pad1.20x1.40mm_HandSolder
R5: 10K; R_0805_2012Metric_Pad1.20x1.40mm_HandSolder
R6, R7, R8, R9: 20K; R_0805_2012Metric_Pad1.20x1.40mm_HandSolder; not fitted
RV1: 18V MOV MVR1206-180G; R_1206_3216Metric_Pad1.30x1.75mm_HandSolder
U1: IS31FL3733-TQ; TQFP-48-1EP_7x7mm_P0.5mm_EP5x5mm
U2: AMS1117-5.0; SOT-223-3_TabPin2

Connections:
3.3V: C4.1, J6.4, R3.1, R4.1, R5.2, R8.1, R9.1, U1.39 (VIO)
5V: C1.1, C3.1, C7.1, C8.1, C9.1, J6.3, JP4.1 (A), JP8.1 (A), R5.1, U1.20 (PVCC), U1.29 (PVCC), U1.37 (AVCC), U1.38 (DVCC), U2.2 (VO)
12V: C2.1, F1.2, J6.2, U2.3 (VI)
/RSET: R2.1, U1.35 (RSET)
ADDR1: JP5.2 (B), JP6.2 (B), JP7.2 (B), JP8.2 (B), R7.1, U1.43 (ADDR1)
ADDR2: JP1.2 (B), JP2.2 (B), JP3.2 (B), JP4.2 (B), R6.1, U1.44 (ADDR2)
GND: C1.2, C2.2, C3.2, C4.2, C7.2, C8.2, C9.2, D1.2 (A), J4.4, J4.5, J4.6, J5.4, J5.5, J5.6, J6.5, J6.6, JP1.1 (A), JP5.1 (A), R1.2, R2.2, R4.2, R6.2, R7.2, RV1.2, U1.5 (PGND), U1.12 (PGND), U1.34 (AGND), U1.48 (GND), U1.49 (GND), U2.1 (GND)
IICRST: J4.9, J5.9, J6.7, R1.1, U1.47 (IICRST)
SCL: J4.8, J5.8, J6.10, JP3.1 (A), JP7.1 (A), R9.2, U1.42 (SCL)
SDA: J4.7, J5.7, J6.9, JP2.1 (A), JP6.1 (A), R8.2, U1.41 (SDA)
SDB: J4.10, J5.10, J6.8, R3.2, U1.46 (~SDB)
SINK_{00}: J1.1, U1.2 (SW1)
SINK_{01}: J1.2, U1.3 (SW2)
SINK_{02}: J1.3, U1.4 (SW3)
SINK_{03}: J1.4, U1.6 (SW4)
SINK_{04}: J2.1, U1.7 (SW5)
SINK_{05}: J2.2, U1.8 (SW6)
SINK_{06}: J2.3, U1.9 (SW7)
SINK_{07}: J2.4, U1.10 (SW8)
SINK_{08}: J3.1, U1.11 (SW9)
SINK_{09}: J3.2, U1.13 (SW10)
SINK_{10}: J3.3, U1.14 (SW11)
SINK_{11}: J3.4, U1.15 (SW12)
SRC_{00}: J1.5, J2.5, J3.5, U1.16 (CS1)
SRC_{01}: J1.6, J2.6, J3.6, U1.17 (CS2)
SRC_{02}: J1.7, J2.7, J3.7, U1.18 (CS3)
SRC_{03}: J1.8, J2.8, J3.8, U1.19 (CS4)
SRC_{04}: J1.9, J2.9, J3.9, U1.21 (CS5)
SRC_{05}: J1.10, J2.10, J3.10, U1.22 (CS6)
SRC_{06}: J1.11, J2.11, J3.11, U1.23 (CS7)
SRC_{07}: J1.12, J2.12, J3.12, U1.24 (CS8)
SRC_{08}: J1.13, J2.13, J3.13, U1.25 (CS9)
SRC_{09}: J1.14, J2.14, J3.14, U1.26 (CS10)
SRC_{10}: J1.15, J2.15, J3.15, U1.27 (CS11)
SRC_{11}: J1.16, J2.16, J3.16, U1.28 (CS12)
SRC_{12}: J1.17, J2.17, J3.17, U1.30 (CS13)
SRC_{13}: J1.18, J2.18, J3.18, U1.31 (CS14)
SRC_{14}: J1.19, J2.19, J3.19, U1.32 (CS15)
SRC_{15}: J1.20, J2.20, J3.20, U1.33 (CS16)
VIN: D1.1 (K), F1.1, J4.1, J4.2, J4.3, J5.1, J5.2, J5.3, J6.1, RV1.1

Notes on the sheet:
3v3 VIO ref
Emergency IIC Pull-Ups
To configure at solder time DNP resistors set a default address--skippable
Upstream to IIC Concentrator
IIC address selection See IS31FL3733B datasheet
The concentrator board should have enough pull-oomph without this--but just in case. RECONFIGURE ABOVE DIVIDER, 1K/2K
Power Input & Shaping
LED Panel Connectors Each 4x16
We may wish to daisy-chain at assembly time

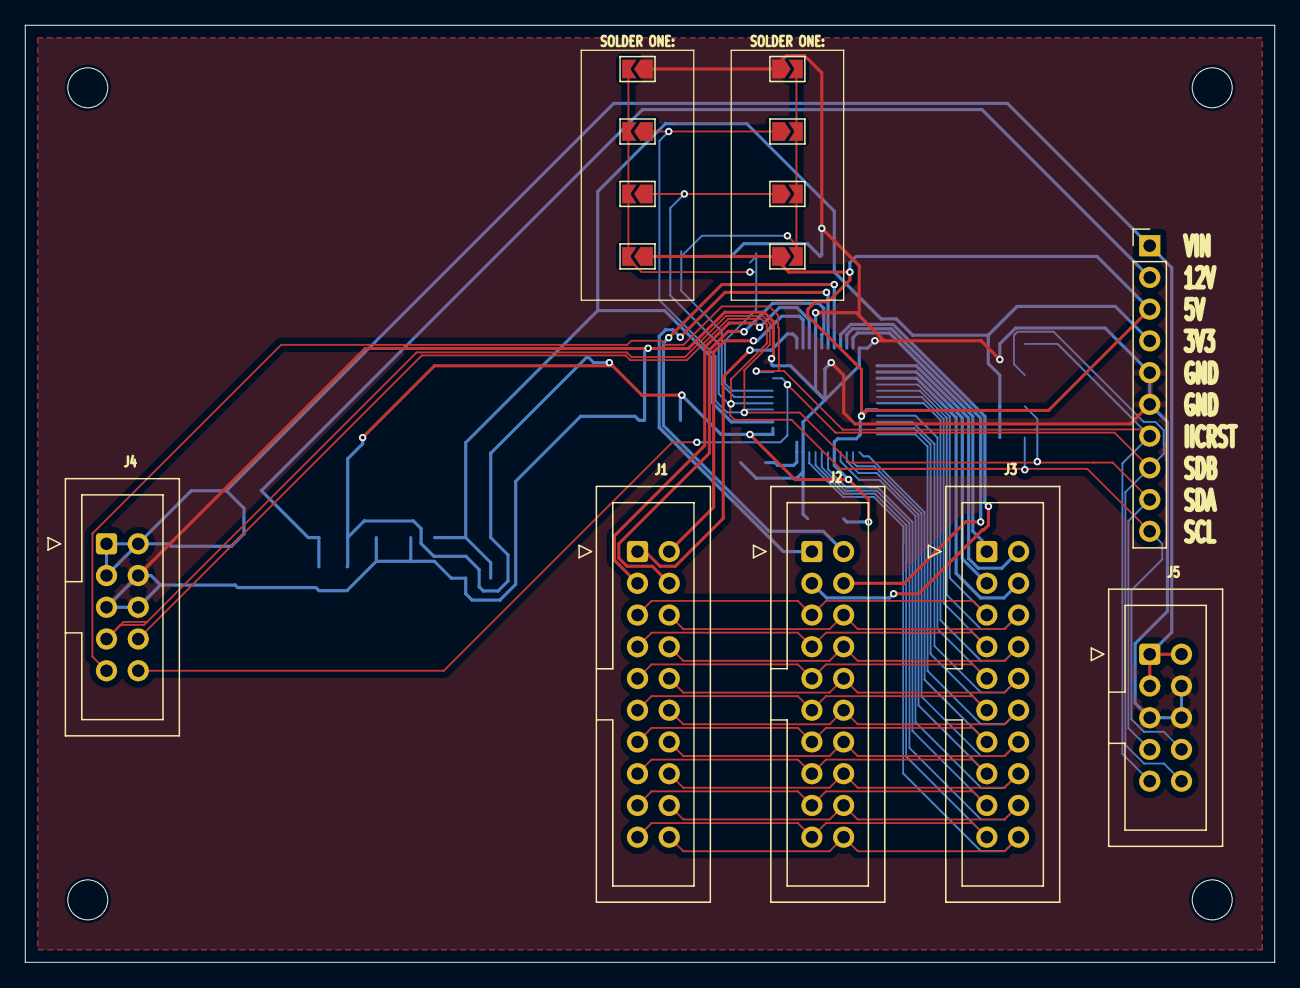
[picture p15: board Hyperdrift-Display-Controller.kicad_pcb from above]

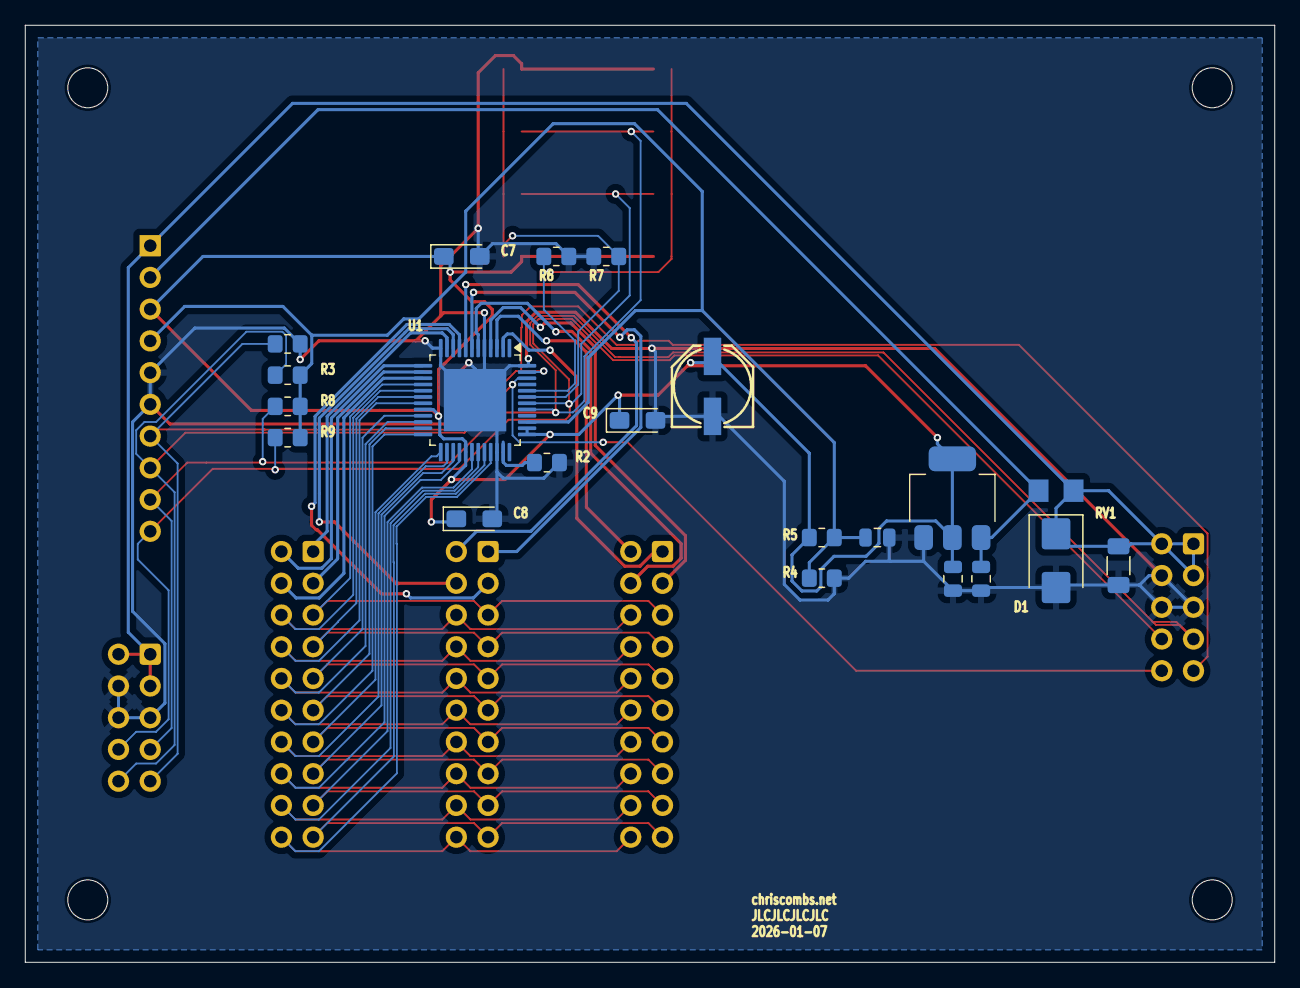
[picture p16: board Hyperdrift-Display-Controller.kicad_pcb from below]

Board: 2 copper layers, 100.0 x 75.0 mm, 39 parts (21 on the bottom side), 40 nets.

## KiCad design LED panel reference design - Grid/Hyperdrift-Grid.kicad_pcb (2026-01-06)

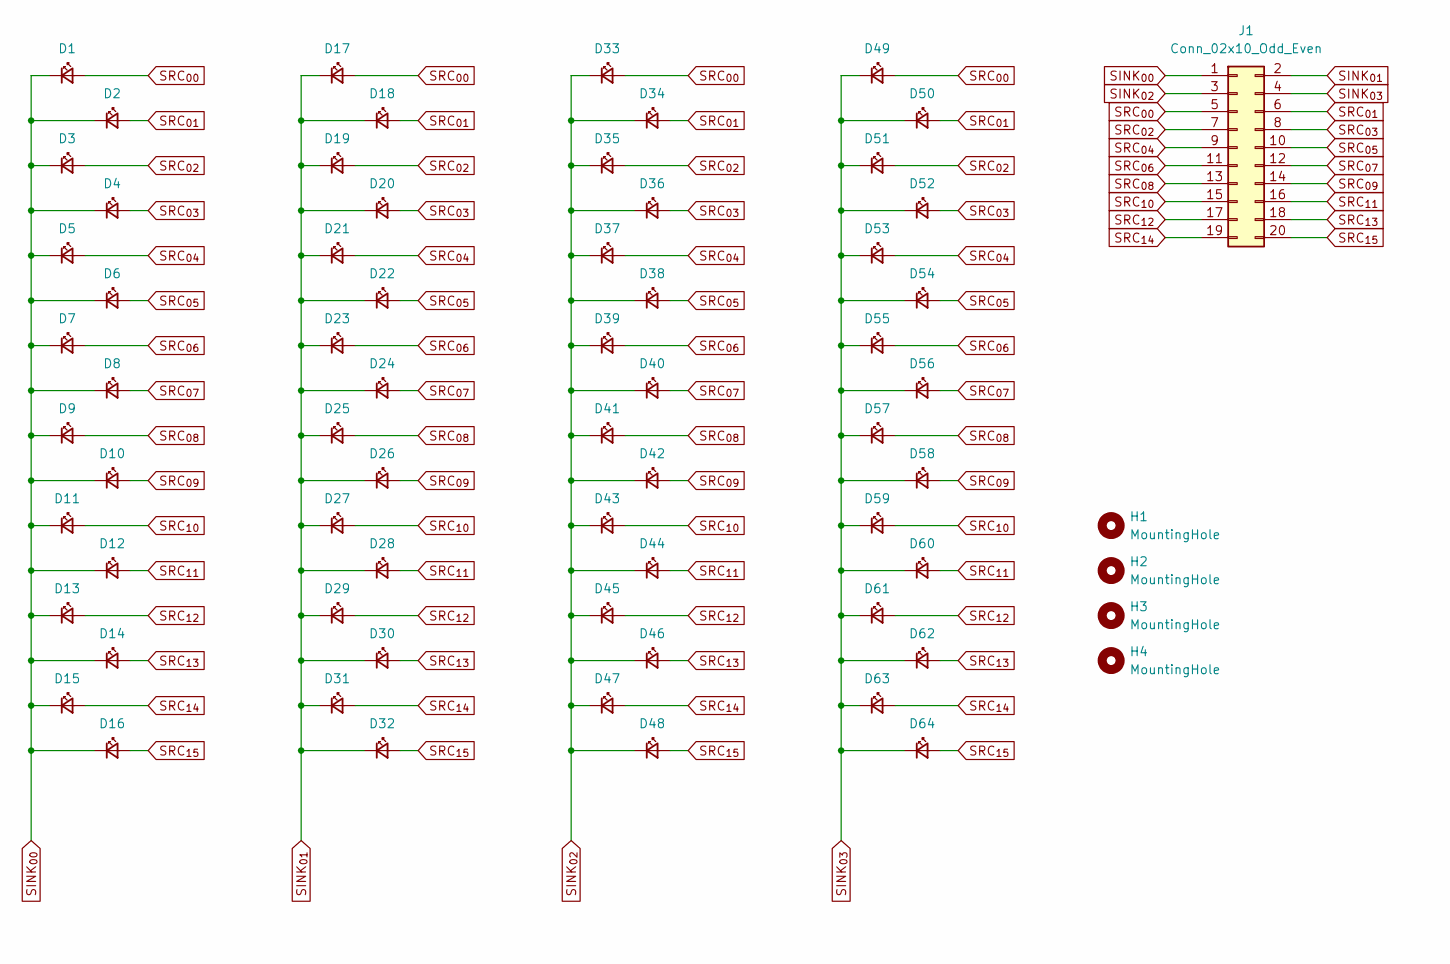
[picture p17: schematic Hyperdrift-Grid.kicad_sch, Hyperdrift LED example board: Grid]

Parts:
D1, D2, D3, D4, D5, D6, D7, D8, D9, D10, D11, D12, D13, D14, D15, D16, D17, D18, D19, D20, D21, D22, D23, D24, D25, D26, D27, D28, D29, D30, D31, D32, D33, D34, D35, D36, D37, D38, D39, D40, D41, D42, D43, D44, D45, D46, D47, D48, D49, D50, D51, D52, D53, D54, D55, D56, D57, D58, D59, D60, D61, D62, D63, D64: LED; LED_D5.0mm
H1, H2, H3, H4: MountingHole; MountingHole_3.2mm_M3
J1: Conn_02x10_Odd_Even; IDC-Header_2x10_P2.54mm_Vertical

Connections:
SINK_{00}: D1.1 (K), D2.1 (K), D3.1 (K), D4.1 (K), D5.1 (K), D6.1 (K), D7.1 (K), D8.1 (K), D9.1 (K), D10.1 (K), D11.1 (K), D12.1 (K), D13.1 (K), D14.1 (K), D15.1 (K), D16.1 (K), J1.1
SINK_{01}: D17.1 (K), D18.1 (K), D19.1 (K), D20.1 (K), D21.1 (K), D22.1 (K), D23.1 (K), D24.1 (K), D25.1 (K), D26.1 (K), D27.1 (K), D28.1 (K), D29.1 (K), D30.1 (K), D31.1 (K), D32.1 (K), J1.2
SINK_{02}: D33.1 (K), D34.1 (K), D35.1 (K), D36.1 (K), D37.1 (K), D38.1 (K), D39.1 (K), D40.1 (K), D41.1 (K), D42.1 (K), D43.1 (K), D44.1 (K), D45.1 (K), D46.1 (K), D47.1 (K), D48.1 (K), J1.3
SINK_{03}: D49.1 (K), D50.1 (K), D51.1 (K), D52.1 (K), D53.1 (K), D54.1 (K), D55.1 (K), D56.1 (K), D57.1 (K), D58.1 (K), D59.1 (K), D60.1 (K), D61.1 (K), D62.1 (K), D63.1 (K), D64.1 (K), J1.4
SRC_{00}: D1.2 (A), D17.2 (A), D33.2 (A), D49.2 (A), J1.5
SRC_{01}: D2.2 (A), D18.2 (A), D34.2 (A), D50.2 (A), J1.6
SRC_{02}: D3.2 (A), D19.2 (A), D35.2 (A), D51.2 (A), J1.7
SRC_{03}: D4.2 (A), D20.2 (A), D36.2 (A), D52.2 (A), J1.8
SRC_{04}: D5.2 (A), D21.2 (A), D37.2 (A), D53.2 (A), J1.9
SRC_{05}: D6.2 (A), D22.2 (A), D38.2 (A), D54.2 (A), J1.10
SRC_{06}: D7.2 (A), D23.2 (A), D39.2 (A), D55.2 (A), J1.11
SRC_{07}: D8.2 (A), D24.2 (A), D40.2 (A), D56.2 (A), J1.12
SRC_{08}: D9.2 (A), D25.2 (A), D41.2 (A), D57.2 (A), J1.13
SRC_{09}: D10.2 (A), D26.2 (A), D42.2 (A), D58.2 (A), J1.14
SRC_{10}: D11.2 (A), D27.2 (A), D43.2 (A), D59.2 (A), J1.15
SRC_{11}: D12.2 (A), D28.2 (A), D44.2 (A), D60.2 (A), J1.16
SRC_{12}: D13.2 (A), D29.2 (A), D45.2 (A), D61.2 (A), J1.17
SRC_{13}: D14.2 (A), D30.2 (A), D46.2 (A), D62.2 (A), J1.18
SRC_{14}: D15.2 (A), D31.2 (A), D47.2 (A), D63.2 (A), J1.19
SRC_{15}: D16.2 (A), D32.2 (A), D48.2 (A), D64.2 (A), J1.20

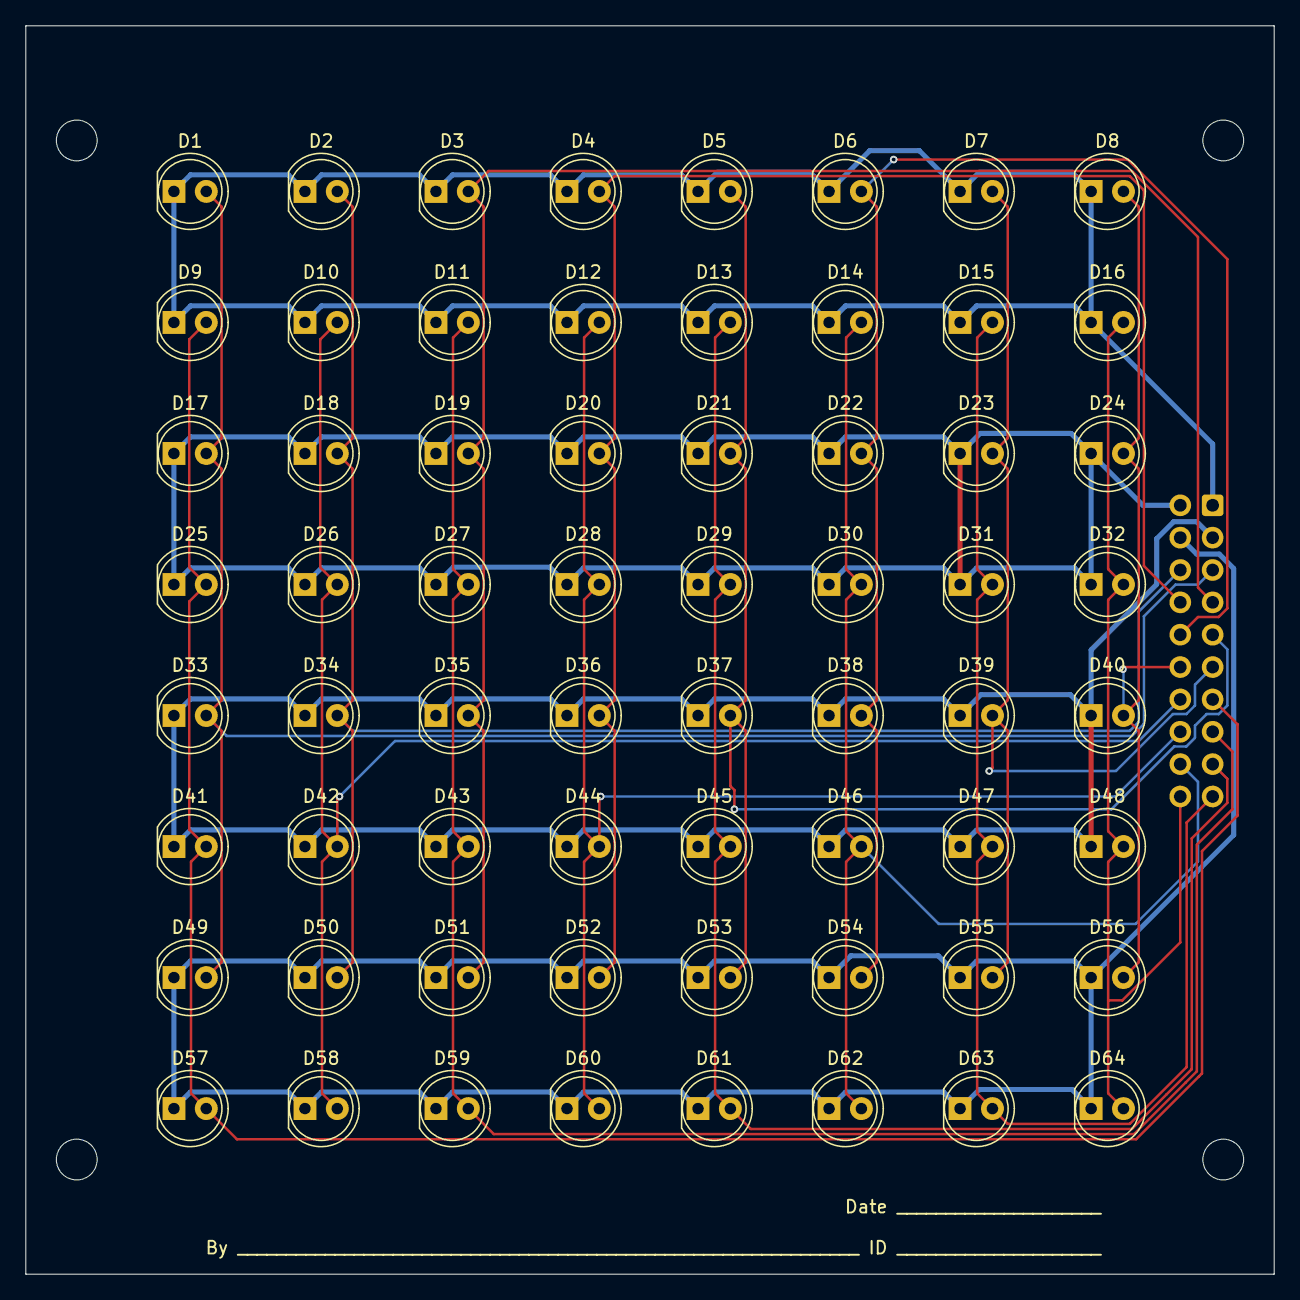
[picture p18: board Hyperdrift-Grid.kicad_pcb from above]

Board: 2 copper layers, 98.0 x 98.0 mm, 69 parts (1 on the bottom side), 20 nets.

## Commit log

2026-01-06 Initial working version
    [Hyperdrift-Grid-B_Cu.gbr, Hyperdrift-Grid-B_Mask.gbr, Hyperdrift-Grid-B_Paste.gbr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]
2026-01-06 Update pixel-grid.py and Hyperdrift-Mechanical spec for LED panels.pdf
2026-01-07 Add Hyperdrift-Display-Controller
    [Hyperdrift-Display-Controller-B_Cu.gbr, Hyperdrift-Display-Controller-B_Mask.gbr, Hyperdrift-Display-Controller-B_Paste.gbr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]
2026-01-07 Add ground pour for Hyperdrift-Display-Controller
    [Hyperdrift-Display-Controller-B_Cu.gbr, Hyperdrift-Display-Controller-B_Mask.gbr, Hyperdrift-Display-Controller-B_Paste.gbr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]
